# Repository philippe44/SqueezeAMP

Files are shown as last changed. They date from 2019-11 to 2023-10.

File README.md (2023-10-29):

# SqueezeAMP: an all-in-one audio sub-system

NOTE: for clarity reasons, I've created a branch 3.x which is the new default. I'll remove all references to PCB before 3.11 in that branch. Look at "master" to have history

This design can be used as a general all-in-one audio subsystem, but it's specially made to match the [SqueezeESP project](https://github.com/philippe44/squeezelite-esp32).
It includes the following:

- Espressif's WROVER board based on ESP32 WiFi/BT chipset (built-in antenna)
- WiFi / BT connectivity
- TI's TAS575x stereo class-D amplifier for up to 2x20W (careful with heat dissipation)
- Built-in battery charger (2 or 3 Li-Ion cells in serie) and automatic switch between battery and main
- Direct speaker output
- Jack 3.5mm for analogue line-out (with insertion detection) ==> <strong>this NOT supposed to be a headset output but it seems to drive enough for small 3 pins headphones at decent volume (need to check)</strong>
- SDPIF optical output
- Infrared Receiver
- Connector for 8 extra general purpose I/O (SPI, I2C, I2S, GPIO ...) ==> can add screen, buttons, rotary encoder ...
- 2 pins (1.27mm) on/off header (off mode consumes about 0.3mA on battery, a few tweaks can bring it down to 0.1 mA)
- 2 pins (1.27mm) GPI/sensor header (see ESP32 documentation about sensor_vn and sensor_vp)
- 2 pins (1.27mm) for 3.3V/GND
- 6 pins (2.54mm) header provide 3.3V (output), GND, reset and serial flash download (boot, rx, tx - which can be reused as general purpose IO)
- 2.5mm Power Jack with Vcc 5...16V (20V under certain conditions see note on power supply below)
- A/D for battery level measure
- Charge LED, bi-color LED

Looking at the board, TOP refers to the side that has the WROVER module and LEFT is where the Power Jack is located

# What can it do

With the squeezelite-esp32 software, you can

- Stream from LMS and send audio to the build-in amplifier, the line-out jack, the spdif connector or another bluetooth speaker. You can also use an external I2S DAC if you connect it to the general purpose 5/8 pins connector and tweak the software. Synchronization works.
- Stream from a Bluetooth device and send audio to the same outputs, except of course for sending to another bluetooth speaker ... There is no guarantee of audio/video synchronization at this point
- Stream from an AirPlay1 device (iPhone, iTunes ...) to the same outputs, including to a bluetooth speaker. Synchronization works.
- Add your own buttons, rotary encoder and map/combine them to various functions (play, pause, volume, next ...
- Use IR control by adding a simple receiver compatible with 38kHz device (no pullup resistor or capacitor needed)
- Add a display like this [one](https://www.buydisplay.com/i2c-blue-0-91-inch-oled-display-module-128x32-arduino-raspberry-pi) which can be directly connected to the 6-pins header. Currently SH1106, SSD1306, SSD1322, SSD1326/7, SSD1351, ST7735 and ST7789 displays are supported.

A small 0.91 display like [this one](https://www.aliexpress.com/item/1005001680040131.html) with [low profile connector](https://www.aliexpress.com/item/4000147221999.html) can be directly connected to the 6 pins 2.54 mm connector and nicely fits inside the case. Use the following settings 
- display_config -> I2C,driver=SSD1306,width=128,height=32
- i2c_config -> sda=3,scl=1,port=1,speed=600000

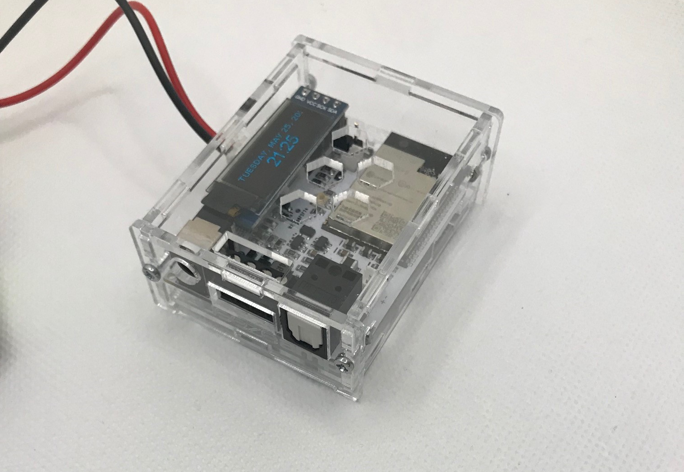
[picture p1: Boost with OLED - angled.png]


This casing is in the *case* repository and has been made by Chris Hill who deserves all credits for this really great design

# Tools, source and BOM

I'm using [diptrace](https://diptrace.com) for schematics and routing which is free up to 300 pins. I had to do a few custom components and patterns, let me know if they are missing or if you cannot use the free version, I'll try to do some export to other PCB formats if needed
You can order the PCB directly from PCBway [here](https://www.pcbway.com/)
There is an excel file with is the BOM extract from diptrace and another one that points to all components from DigiKey
The WROVER documentation can be found on [Espressif](http://www.espressif.com) site
Download tool is [here](https://www.espressif.com/en/support/download/other-tools)

## Connectors & WROVER pin assignments

There are 2 PCB versions, a basic and a boost option for each one (see below for basic/boot differences).

All connectors are through-holes so that you can not populate them and directly solder wires if you want to use the board inside another equipment (Under parenthesis is the WROVER pin number).

- J1: power jack
- J2: audio jack 
	- 4: (6 - IO34) Detect ==> has pull-up and should be set to ground to detect jack insertion
- J3: main header 
	- 1: GND
	- 2: 3.3V output
	- 3: TX (35) IO1
	- 4: RX (34) IO3
	- 5: EN/reset (3) ==> connect to RTS if possible
	- 6: Boot (25) IO0 ==> pull down at reset to enter download mode (connect to DTR if possible). It's also connected to the IR
- J4/J9: battery connector (double footprint)
	- 1: +
	- 2: -
- J5: speaker connector
	- 1: L+ (square pad)
	- 2: L-
	- 3: R-
	- 4: R+
- J6: IO extension connector (note that a right-angle and a straight version exist)
	- 1: (26) IO4
	- 2: (29) IO5
	- 3: (30) IO18
	- 4: (31) IO19
	- 5: (33) IO21
	- 6: (35) IO0/GND depending on S2
	- 7: (36) IO22
	- 8: (37) IO23
- J7: on/off (on when floating/open)	
	- 1: GND
	- 2: ENable ==> short with pin 1/GND to switch off 3.3V power
- J8: Input/Sensor connector (inputs only, no internal pull-up)
	- 1: (5) IO39
	- 2: (4) IO36
- J10: Power source
	- 1: 3.3V
	- 2: GND
- S2: select J6 pin 6 between GND and IO2
- Green LED: (14) IO12, active low
- Red LED: (16) IO13, active low
- TAS575x Speaker mute (13) IO14
- TAS575x Speaker fault (24) IO2
- TAS575x SCL/SDA: (11) IO26 / (12) IO27
- TAS575x I2S WS/SD/CLK: (10) IO25 / (8) IO32 / (9) IO33
- SPDIF: (23) IO15

<strong>Note that is no reverse polarity protection on the battery pins, so be careful as it will toast the power switch TPS22810 and probably the PCB itself. There is polarity protection on the main.</strong>

# Flash download

For at least initial download, you need a serial connection with ideally RX/TX/RTS/DTR and at least RX/TX. There is no build-in converter. 

Connect RX/TX to J3 pin header. If you don't have DTR/boot, you must connect DWL to ground while resetting (simply put a wire on pin 6 of J3 and connect it to any ground) and if don't have RTS/reset, press the tiny reset button or short the RST pin to ground. 

The esp32 will enter download and you'll be able to update the software, as described on the squeezelite-esp32 site. This procedure is rarely needed as the software supports OTA update.

Follow the instructions [here](https://github.com/philippe44/squeezelite-esp32) or have fun with your own software (see also espressif [guide](https://github.com/espressif/esptool/wiki/ESP32-Boot-Mode-Selection))

# Usage comments

Now that since displays, rotary encoder and buttons are supported by the firmware, you need power and more IOs. You can use power from J6 of course, but if you use it to directly connect a display like [this](https://www.amazon.com/MakerFocus-Display-SSD1306-3-3V-5V-Arduino/dp/B0761LV1SD/) (and remember that since PCB 3.x, it is a direct board-to-board fit) you might want another source so you can use J10. You can as well use extended J6 pin above or below to grab 3.3V from there.

The benefit of changing J6's pin 6 to GND is, for example, to bring a GND wire to a button expansion board of your own. There is no need of Vcc as the ESP32 has optional pull-up. Still, if you want a Vcc, you can use one GPIO as a supply, with a maximum of 40mA per pin. That would allow you to use a single connector for the IOs and a display on J6. You could have Vcc, GND, 3 pins for a rotary, play, back, vol+, vol- which is a pretty good UI.

All 2-pin connectors have been changed to support standard 1.25mm connectors like [this](https://www.ebay.ca/itm/50Set-Micro-JST1-25-2Pin-Connector-Plug-with-Wire-150mm-28AWG/182056647596) so that you can find pre-wired female cables and not go through the pain of using these tiny crimps. The male header is a really tight fit on the PCB, but it works. You can also always solder wires if you want  to.

<strong>All GPIO have internal pull-up/down that you can set by software, so in most cases you don't need to bring power to buttons/encoder board, except if you use J8. These are inputs only and have no pull-up, so you need to add them on your IO board.</strong>

According to TAS57xx datasheet, if you short L+/L- and R+/R- you can use the chip in post-filtered mono BTL mode. Sounds a bit strange and I've not tried as of this writing, but if it might be handy to do a mono (more powerful) speaker.

# Populating options

System is modular and you can pretty much build each sub-part independently. 

If you don't want battery, don't populate charger, undervoltage detection and power OR and boost (on the boost option, see below). This is all top upper and middle right & left side of the PCB. You can short the large Schottky diode on the bottom side, but I recommend you keep it just in case.

If you don't want the amplifier, don't populate the bottom side, except for the power diode and the optical connector's decoupling capacitor (if you want SPDIF optical). In that case, note that the analogue output will *not* be available.

The SPDIF is always available, it just requires the WROVER module (which should at least always be here ...). 

The battery connector is the angled version of the classical short 2 pins JST. You can use a longer version if you want the pins to extend a bit beyong the PCB (like the jack connector). You can also use a vertical connector [here]( https://www.digikey.ca/product-detail/en/jst-sales-america-inc/B2B-XH-A(LF)(SN)/455-2247-ND/1651045)

# Power options

I've been through a lot of back and forth about power. To charge 3-LiIon cells, the LT3652 requires at least 16V (Vbatt + 3.3V). But when powered with 16V, the TAS575x produces a fair bit of heat while it almost does none at 12V. Similar, the original design charging rate was 1A, but that got the LT3652 and inductor super hot, so I've reduced is to 0,66A (8W max). The rate is 0.1/R7 so you can tweak it if you want, on paper the design is capable of 1A.

When using 2 cells, a 12V power supply is sufficient which is ideal for the TAS575x, but then when used on battery the audio power is much less as the battery will provide 6~8.4V. Charging rate in that case is 0.75A. 

So finally, I have 2 PCB options, the boost being the most versatile one but the most expensive as well. If you decide to not populate the battery charging, you can skip the rest of that section.

## Basic design

2 cells mode is the simplest option. Power supply can be 12-20V, but 12V is recommended to optimize heat dissipation unless you want maximum amplifier power.  

In 3 cells mode, the power supply must be 16-20V and a few components must be changed

- R8 (412k) ==> 340k
- R9 (634k)==> 953k
- R11 (25.5k) ==> 15.8k
- D5 (2.4V Zener) ==> 5~8V Zener (I use 5.1)
- R7 (0.13) ==> 0.16

In both case, if you limit the power supply to 16V, you can use 25V for all capacitors which saves a fair bit of cost for the 22µF. It does not change anything for others (indeed 50V can a be cheaper option for 100nF for example).

## Boost design

This PCB option include a boost converter so that power supply can be 12V even in 3 cells modes. With that, the TAS575x is always powered with ~12V which is the ideal ratio heat/amplifier power. The boost converter will up the power supply to comply with LT3652 requirement of Vcc > VBat + 3.3V. You could even power it with 5V and it will charge the 3-cells battery **but** it will still power the amplifier at 5V (or whatever you put in).

## (Executive) Summary

- don't want battery, use the basic version and maybe do not populate all the charger-related components
	- want to minimize heat: use 12V
	- want maximum audio power: use up to 20V
- want battery
	- don't need too much audio power when battery powered: choose basic (2 cells) and power it with 12V. 
	- want more audio power: 
		- don't care much about amplifier's heat: choose basic (3 cells) and power it with 16+V (put a sink on the TAS575X and the exposed pad). 
	- want to minimize amplifier's heat, choose boost (3 cells) and power it with 12V
	- want simply to power with less than 12V, choose boost (2 or 3 cells). 

# Limitation & Disclaimer

This contains a power amplifier and a charger on a small board, so it gets pretty hot when used at high power. I've added a small exposed copper area where you can add a heatsink and also use a fan to help cooling down, but I cannot guarantee that this design works well and safely with continuous high volume. My own use is at moderate volume.

Similarly, the charger is for Li-Ion and such cells have inherent safety issues. It's using a LT3652, which is a good charger that takes care of battery maintenance, but there is no thermal management, so be careful and ALWAYS use protected Li-Ion cells. There is battery undervoltage detection on board so that the systems shuts off when battery voltage is too low. There is no under voltage detection for main supply.

<strong>This is by no mean a professional design so use it at your own risk. I will not be liable for any issue caused by that board</strong>. I'm making it public in case somebody with enough knowledge will find it useful, so know what you're doing first. Similarly, this is not an audiophile design, so please do not complain or ask me for some linear power or 32 bits / DSD insanities. The SqueezeESP software can do 16 bits @ 192 kHz which is way more than enough, in fact 48kHz/16 should be sufficient. 

Credits to @Aki7 for the picture below
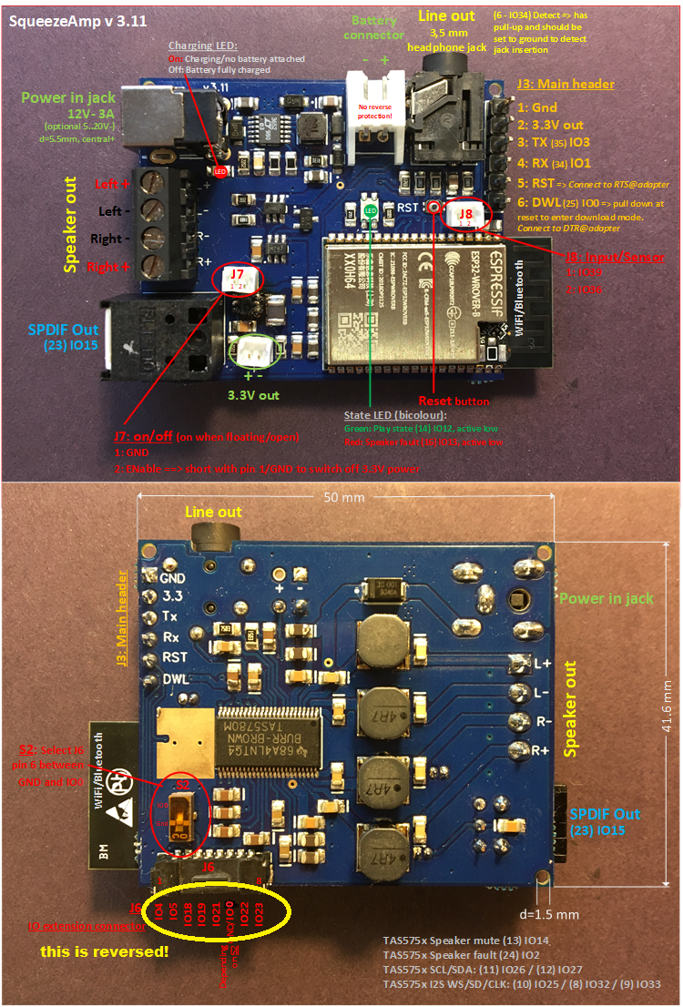
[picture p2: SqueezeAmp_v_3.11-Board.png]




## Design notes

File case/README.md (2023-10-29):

The V1 is an old casing that has not been continued.

The V2 is made of 6 pieces and requires 4 screws to be assembled. It exists as well in thing and thick (battery) versions.

There is a root DXF file that contains all the drawings for acrylic laser cuts, tolerances should be part of cutting.

The DXF has been adjusted to a 3D version that adds tolerances for 3D printing with a 2mm thickness.

A few STL are provides as well

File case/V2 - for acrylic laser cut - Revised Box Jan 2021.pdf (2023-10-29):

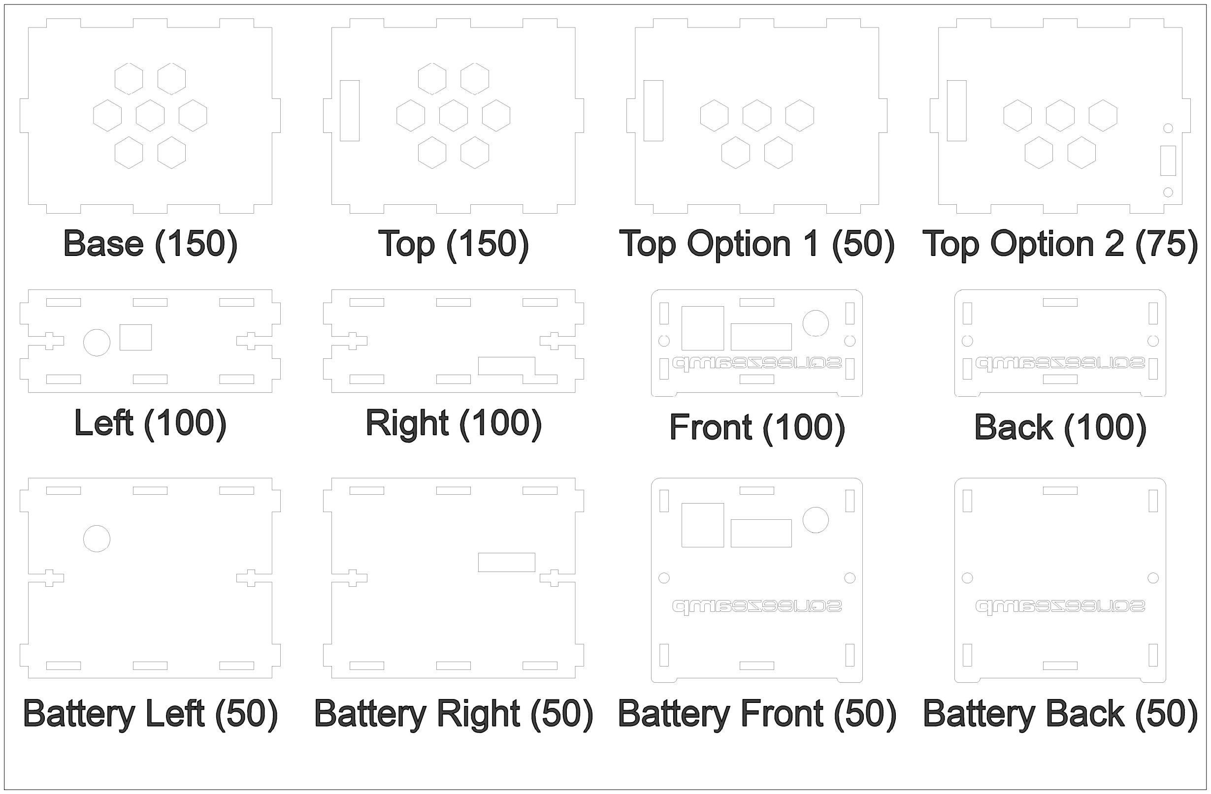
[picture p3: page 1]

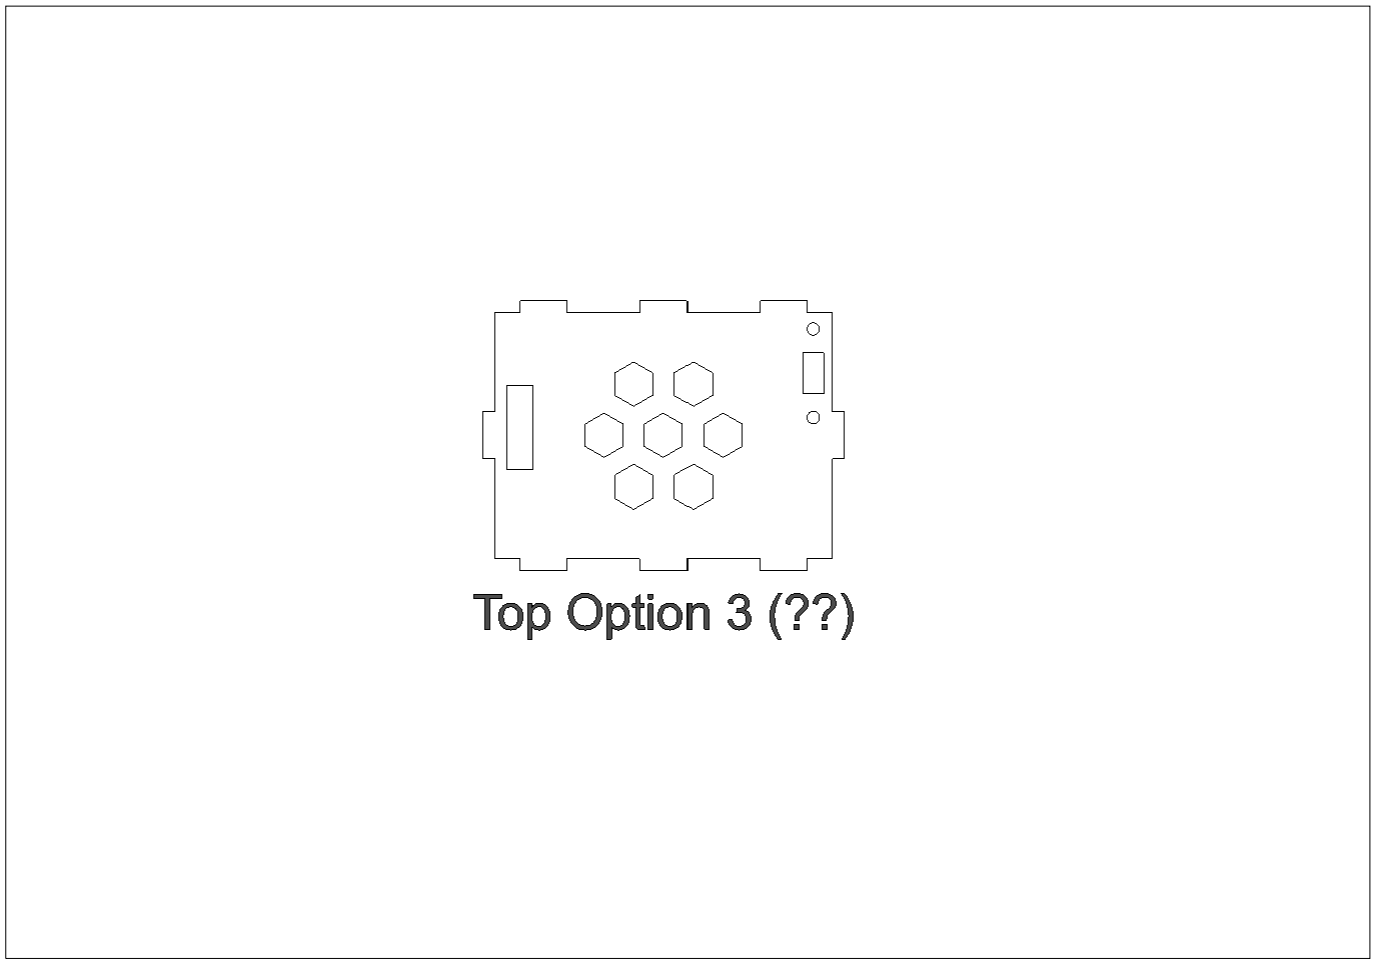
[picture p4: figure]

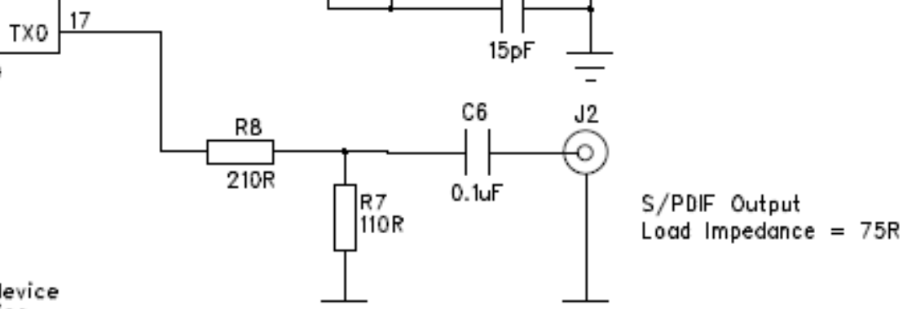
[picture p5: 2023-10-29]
ttl2coax.png

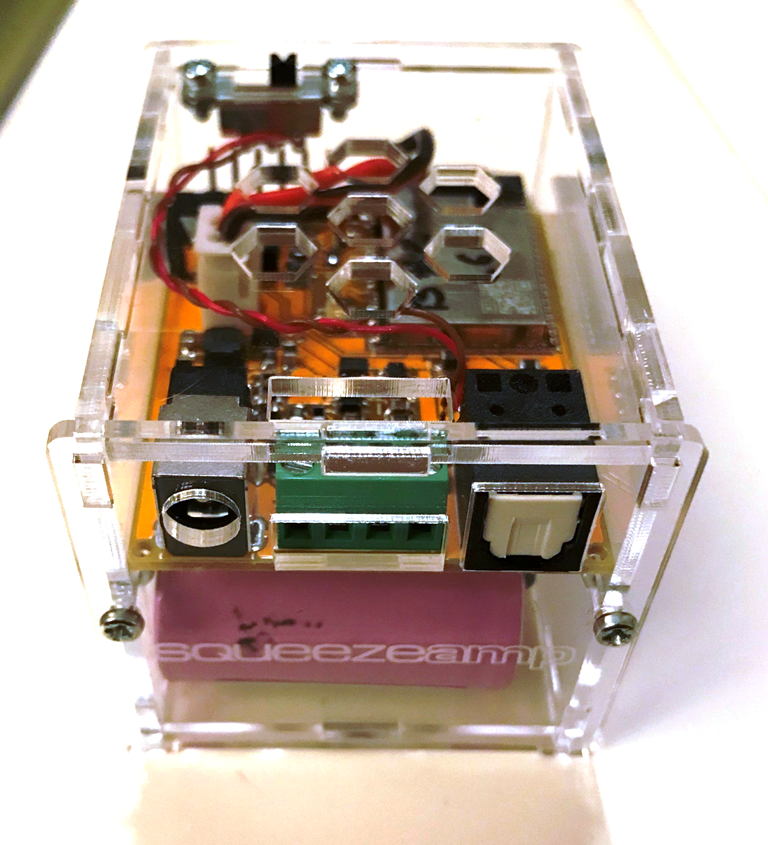
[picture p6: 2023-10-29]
Thick.png

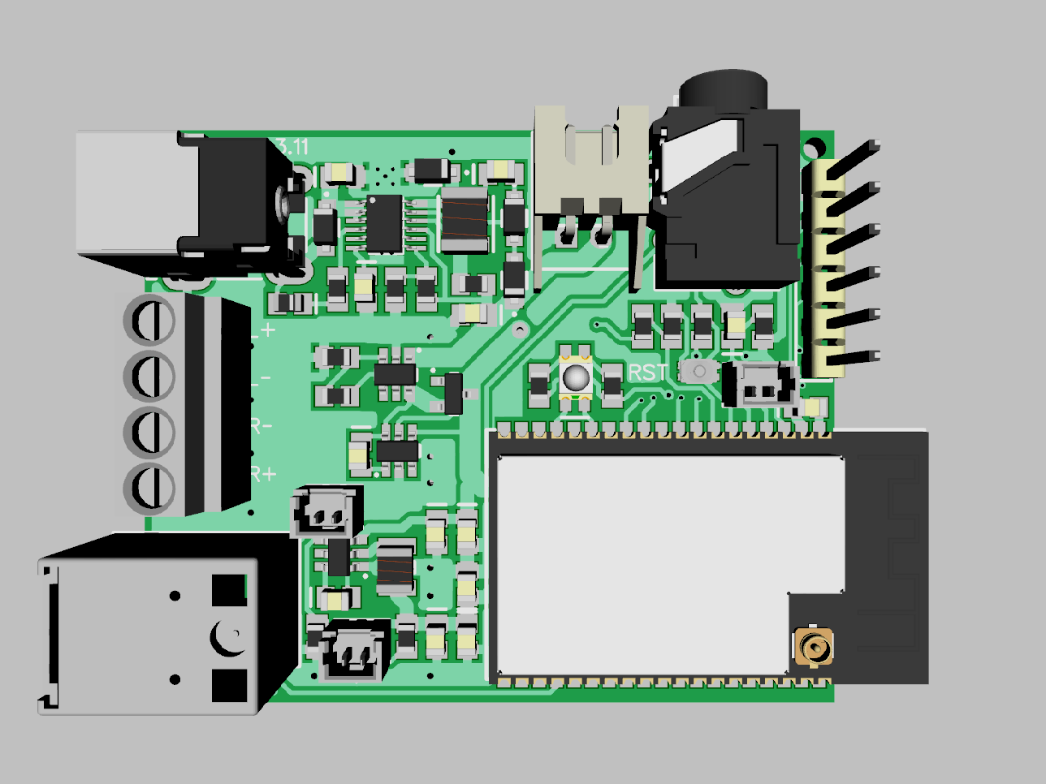
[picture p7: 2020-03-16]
top.png

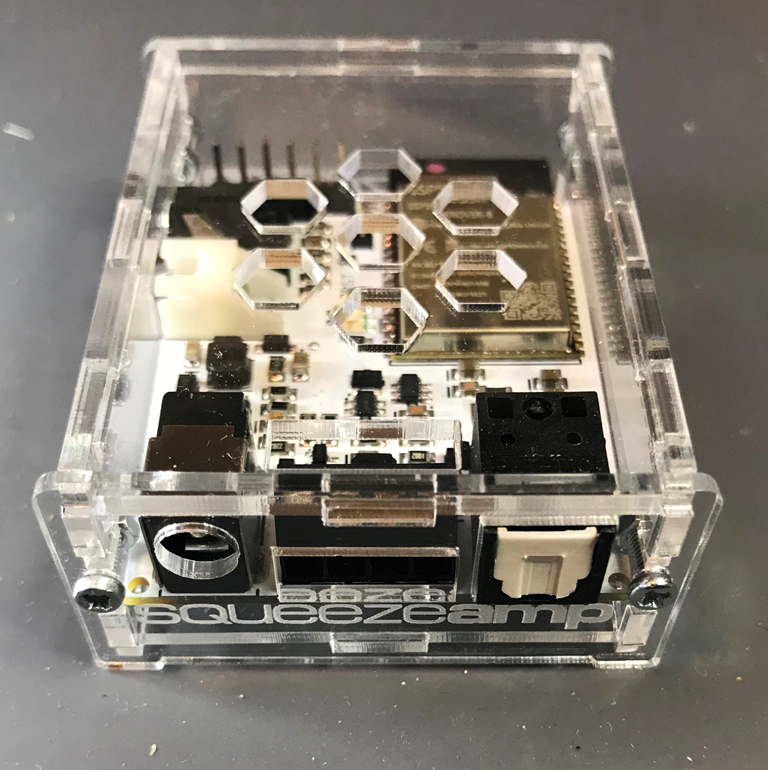
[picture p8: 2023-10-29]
Thin.png

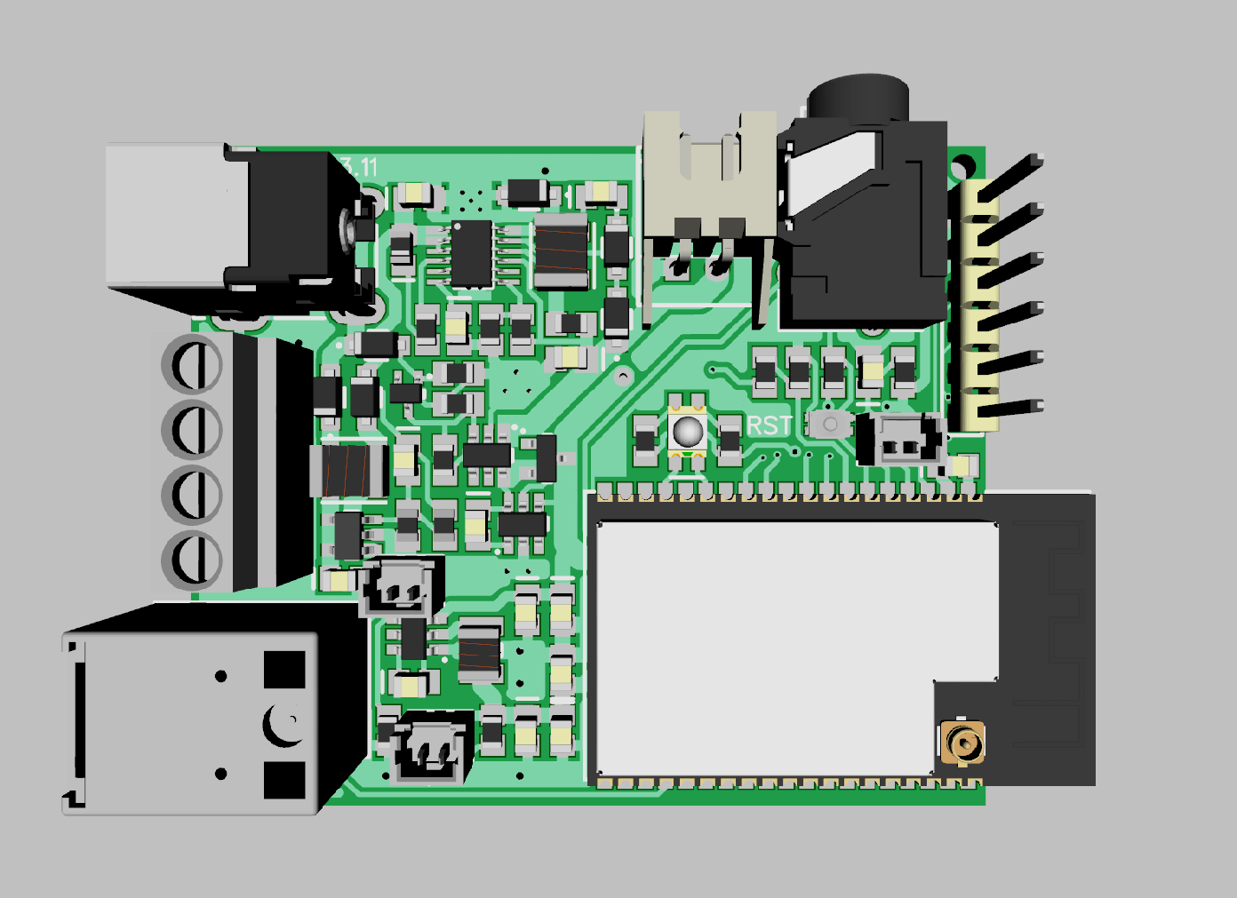
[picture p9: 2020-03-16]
top-boost.png

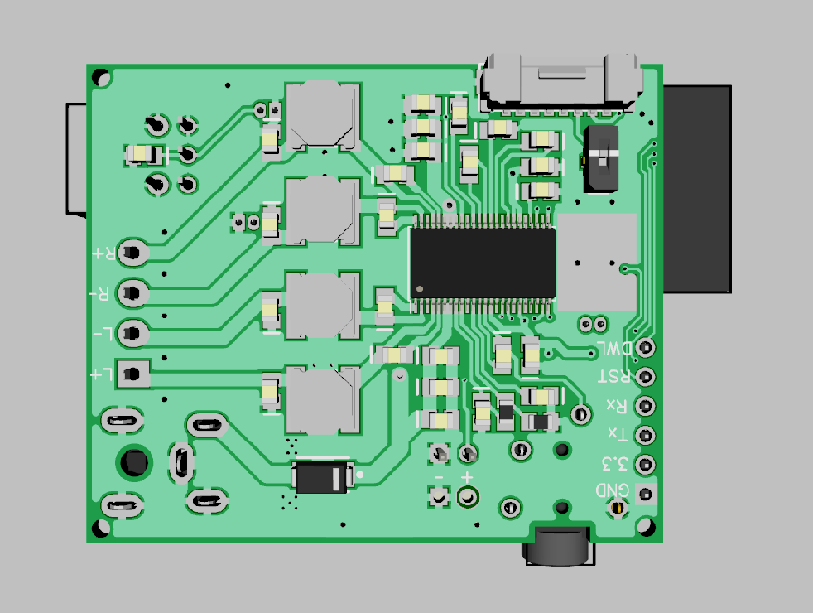
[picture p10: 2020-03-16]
bottom.png

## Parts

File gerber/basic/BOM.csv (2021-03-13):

RefDes | Value | Name | Part
C1 | 22uF 35V | CAP_0805 | https://www.digikey.ca/product-detail/en/tdk-corporation/C2012X5R1V226M125AC/445-14428-1-ND/3956094
C2 | 1uF 35V | CAP_0805 | https://www.digikey.ca/product-detail/en/samsung-electro-mechanics/CL21B105KBFNFNE/1276-2928-1-ND/3891014
C3 | 100nF 35V | CAP_0805 | https://www.digikey.ca/product-detail/en/yageo/CC0805ZRY5V9BB104/311-1361-1-ND/2103145
C4 | 100nF 35V | CAP_0805 | https://www.digikey.ca/product-detail/en/yageo/CC0805ZRY5V9BB104/311-1361-1-ND/2103145
C5 | 22uF 35V | CAP_0805 | https://www.digikey.ca/product-detail/en/tdk-corporation/C2012X5R1V226M125AC/445-14428-1-ND/3956094
C6 | 22uF 35V | CAP_0805 | https://www.digikey.ca/product-detail/en/tdk-corporation/C2012X5R1V226M125AC/445-14428-1-ND/3956094
C7 | 22uF 35V | CAP_0805 | https://www.digikey.ca/product-detail/en/tdk-corporation/C2012X5R1V226M125AC/445-14428-1-ND/3956094
C8 | 22uF 35V | CAP_0805 | https://www.digikey.ca/product-detail/en/tdk-corporation/C2012X5R1V226M125AC/445-14428-1-ND/3956094
C9 | 1uF 35V | CAP_0805 | https://www.digikey.ca/product-detail/en/samsung-electro-mechanics/CL21B105KBFNFNE/1276-2928-1-ND/3891014
C10 | 22uF 35V | CAP_0805 | https://www.digikey.ca/product-detail/en/tdk-corporation/C2012X5R1V226M125AC/445-14428-1-ND/3956094
C11 | 1uF 35V | CAP_0805 | https://www.digikey.ca/product-detail/en/samsung-electro-mechanics/CL21B105KBFNFNE/1276-2928-1-ND/3891014
C12 | 1uF 35V | CAP_0805 | https://www.digikey.ca/product-detail/en/samsung-electro-mechanics/CL21B105KBFNFNE/1276-2928-1-ND/3891014
C13 | 1uF 35V | CAP_0805 | https://www.digikey.ca/product-detail/en/samsung-electro-mechanics/CL21B105KBFNFNE/1276-2928-1-ND/3891014
C14 | 2u2F 35V | CAP_0805 | https://www.digikey.ca/product-detail/en/samsung-electro-mechanics/CL21A225KBFNNNE/1276-6702-1-ND/5961561
C15 | 2u2F 35V | CAP_0805 | https://www.digikey.ca/product-detail/en/samsung-electro-mechanics/CL21A225KBFNNNE/1276-6702-1-ND/5961561
C16 | 1uF 35V | CAP_0805 | https://www.digikey.ca/product-detail/en/samsung-electro-mechanics/CL21B105KBFNFNE/1276-2928-1-ND/3891014
C17 | 220nF 35v | CAP_0805 | https://www.digikey.ca/product-detail/en/wurth-electronics-inc/885012207100/732-7675-1-ND/5454302
C18 | 2u2F 35V | CAP_0805 | https://www.digikey.ca/product-detail/en/samsung-electro-mechanics/CL21A225KBFNNNE/1276-6702-1-ND/5961561
C19 | 2u2F 35V | CAP_0805 | https://www.digikey.ca/product-detail/en/samsung-electro-mechanics/CL21A225KBFNNNE/1276-6702-1-ND/5961561
C20 | 680nF 35V | CAP_0805 | https://www.digikey.ca/product-detail/en/tdk-corporation/C2012X5R1H684K125AB/445-14413-6-ND/3960509
C21 | 1uF 35V | CAP_0805 | https://www.digikey.ca/product-detail/en/samsung-electro-mechanics/CL21B105KBFNFNE/1276-2928-1-ND/3891014
C22 | 220nF 35V | CAP_0805 | https://www.digikey.ca/product-detail/en/wurth-electronics-inc/885012207100/732-7675-1-ND/5454302
C23 | 220nF 35V | CAP_0805 | https://www.digikey.ca/product-detail/en/wurth-electronics-inc/885012207100/732-7675-1-ND/5454302
C24 | 220nF 35V | CAP_0805 | https://www.digikey.ca/product-detail/en/wurth-electronics-inc/885012207100/732-7675-1-ND/5454302
C25 | 680nF 35V | CAP_0805 | https://www.digikey.ca/product-detail/en/tdk-corporation/C2012X5R1H684K125AB/445-14413-6-ND/3960509
C26 | 680nF 35V | CAP_0805 | https://www.digikey.ca/product-detail/en/tdk-corporation/C2012X5R1H684K125AB/445-14413-6-ND/3960509
C27 | 680nF 35V | CAP_0805 | https://www.digikey.ca/product-detail/en/tdk-corporation/C2012X5R1H684K125AB/445-14413-6-ND/3960509
C28 | 680nF 35V | CAP_0805 | https://www.digikey.ca/product-detail/en/tdk-corporation/C2012X5R1H684K125AB/445-14413-6-ND/3960509
C29 | 22uF 25V | CAP_0805 | https://www.digikey.ca/product-detail/en/tdk-corporation/C2012X5R1V226M125AC/445-14428-1-ND/3956094
C30 | 22uF 35V | CAP_0805 | https://www.digikey.ca/product-detail/en/tdk-corporation/C2012X5R1V226M125AC/445-14428-1-ND/3956094
C31 | 100nF 35V | CAP_0805 | https://www.digikey.ca/product-detail/en/yageo/CC0805ZRY5V9BB104/311-1361-1-ND/2103145
C32 | 1uF 35V | CAP_0805 | https://www.digikey.ca/product-detail/en/samsung-electro-mechanics/CL21B105KBFNFNE/1276-2928-1-ND/3891014
C36 | 100nF 35V | CAP_0805 | https://www.digikey.ca/product-detail/en/yageo/CC0805ZRY5V9BB104/311-1361-1-ND/2103145
C41 | 22uF 35V | CAP_0805 | https://www.digikey.ca/product-detail/en/tdk-corporation/C2012X5R1V226M125AC/445-14428-1-ND/3956094
C42 | 100nF 35V | CAP_0805 | https://www.digikey.ca/product-detail/en/yageo/CC0805ZRY5V9BB104/311-1361-1-ND/2103145
C43 | 100nF 35V | CAP_0805 | https://www.digikey.ca/product-detail/en/yageo/CC0805ZRY5V9BB104/311-1361-1-ND/2103145
C44 | 22uF 35V | CAP_0805 | https://www.digikey.ca/product-detail/en/tdk-corporation/C2012X5R1V226M125AC/445-14428-1-ND/3956094
C45 | 100nF 35V | CAP_0805 | https://www.digikey.ca/product-detail/en/yageo/CC0805ZRY5V9BB104/311-1361-1-ND/2103145
D1 | LED | 0805 | https://www.digikey.ca/product-detail/en/kingbright/APT2012LSECK-J3-PRV/754-1935-1-ND/5177465
D2 | Schottky 40V 2A | SOD123F | https://www.digikey.ca/product-detail/en/diodes-incorporated/B240S1F-7/B240S1F-7DICT-ND/7784165
D3 | Schottky 40V 2A | SOD123F | https://www.digikey.ca/product-detail/en/diodes-incorporated/B240S1F-7/B240S1F-7DICT-ND/7784165
D4 | Diode 100mA | SOD123F | https://www.digikey.ca/product-detail/en/diodes-incorporated/BAV21HWF-7/BAV21HWF-7DICT-ND/5451809
D5 | Zener 2.4V 100mA | SOD123F | https://www.digikey.ca/product-detail/en/BZT52B2V4+RHG/BZT52B2V4RHGCT-ND/7357321
D6 | Schottky 40V 3A | MBRS340 | https://www.digikey.ca/product-detail/en/diodes-incorporated/B340A-13-F/B340A-FDICT-ND/725054
D8 | Dual LED | 754-1965-1-ND | https://www.digikey.ca/product-detail/en/kingbright/APBD3224LSURKZGKC/754-1965-1-ND/5803684
J1 | Power Jack 2.1 | PJ-047AH | https://www.digikey.ca/product-detail/en/cui-devices/PJ-047AH/CP-047AH-ND/1644577
J2 | 3.5mm Jack 4 points | SJ-43514 | https://www.digikey.ca/product-detail/en/cui-inc/SJ-43514/CP-43514-ND/368146
J3 | 6 pins header 2.54 | CONN | https://www.digikey.ca/product-detail/en/amphenol-icc-fci/68000-406HLF/609-3263-ND/1878471
J4 | Header 2 pin 2.54 mm | Header | https://www.digikey.ca/product-detail/en/jst-sales-america-inc/S2B-XH-A-1(LF)(SN)/455-4226-ND/9961922
J5 | Term Header 4 Pos | WM7860-ND | https://www.digikey.ca/product-detail/en/molex/0393570004/WM7860-ND/1280711
J6 | Molex ML+ 8 pins | Molex MicroLockPlus 8 | https://www.digikey.ca/product-detail/en/molex/5055670871/WM17115CT-ND/7908449
J7 | Header 2 pins 1.27 | 125SH-B-02-TS-SQ | https://www.digikey.ca/product-detail/en/125SH-B-02-TS/2057-125SH-B-02-TS-ND/9830561/
J8 | Header 2 pins 1.27 | 125SH-B-02-TS | https://www.digikey.ca/product-detail/en/125SH-B-02-TS/2057-125SH-B-02-TS-ND/9830561/
J9 | Header 2 pin 2.54 mm | Header | https://www.digikey.ca/product-detail/en/jst-sales-america-inc/S2B-XH-A-1(LF)(SN)/455-4226-ND/9961922
J10 | Header 2 pins 1.27 | 125SH-B-02-TS-SQ | https://www.digikey.ca/product-detail/en/125SH-B-02-TS/2057-125SH-B-02-TS-ND/9830561/
L1 | 4.7uH | 1255AY-4R7M=P3 | https://www.digikey.ca/product-detail/en/murata-electronics-north-america/1255AY-4R7M=P3/490-10812-1-ND/5271554
L2 | 4.7uH | 1255AY-4R7M=P3 | https://www.digikey.ca/product-detail/en/murata-electronics-north-america/1255AY-4R7M=P3/490-10812-1-ND/5271554
L3 | 4.7uH | 1255AY-4R7M=P3 | https://www.digikey.ca/product-detail/en/murata-electronics-north-america/1255AY-4R7M=P3/490-10812-1-ND/5271554
L4 | 4.7uH | 1255AY-4R7M=P3 | https://www.digikey.ca/product-detail/en/murata-electronics-north-america/1255AY-4R7M=P3/490-10812-1-ND/5271554
L5 | 10uH | ASPI-4030S | https://www.digikey.ca/product-detail/en/abracon-llc/ASPI-4030S-100M-T/535-12314-1-ND/4214914
L6 | 22uH | IND_1210 | https://www.digikey.ca/product-detail/en/taiyo-yuden/CBC3225T220MR/587-1626-1-ND/1008241
Q1 | MOFSET-N 2.5A 60V | SOT-23F | https://www.digikey.ca/products/en?keywords=SSM3K318RLFDKR-ND
R1 | 100k | RES_0805 | https://www.digikey.ca/product-detail/en/yageo/RC0805FR-07100KL/311-100KCRCT-ND/730491
R2 | 22k | RES_0805 | https://www.digikey.ca/product-detail/en/yageo/RC0805FR-0722KL/311-22.0KCRCT-ND/730683
R3 | 22k | RES_0805 | https://www.digikey.ca/product-detail/en/yageo/RC0805FR-0722KL/311-22.0KCRCT-ND/730683
R4 | 150K | RES_0805 | https://www.digikey.ca/product-detail/en/yageo/RC0805FR-07150KL/311-150KCRCT-ND/730561
R5 | 270 | RES_0805 | https://www.digikey.ca/product-detail/en/yageo/RC0805JR-07270RL/311-270ARCT-ND/731238
R6 | 680 | RES_0805 | https://www.digikey.ca/product-detail/en/yageo/RC0805FR-07680RL/311-680CRCT-ND/731048
R7 | 0.13 | RES_0805 | https://www.digikey.ca/product-detail/en/yageo/RL0805FR-070R13L/311-.13SCT-ND/1037214
R8 | 634k - 0.1% | RES_0805 | https://www.digikey.ca/en/products/detail/panasonic-electronic-components/ERA-6AEB6343V/3075213
R9 | 412k - 0.1% | RES_0805 | https://www.digikey.ca/en/products/detail/panasonic-electronic-components/ERA-6AEB4123V/3075129
R10 | 110k (0.1%) | RES_0805 | https://www.digikey.ca/product-detail/en/yageo/RC0805FR-07110KL/311-110KCRCT-ND/730507
R11 | 25.5k | RES_0805 | https://www.digikey.ca/product-detail/en/RC0805FR-0725K5L/311-25.5KCRCT-ND/730715
R13 | 750k | RES_0805 | https://www.digikey.ca/product-detail/en/yageo/RC0805FR-07750KL/311-750KCRCT-ND/731082
R14 | 10k | RES_0805 | https://www.digikey.ca/product-detail/en/yageo/RC0805FR-0710KL/311-10.0KCRTR-ND/727535
R15 | 10k | RES_0805 | https://www.digikey.ca/product-detail/en/yageo/RC0805FR-0710KL/311-10.0KCRTR-ND/727535
R16 | 174k | RES_0805 | https://www.digikey.ca/product-detail/en/yageo/RC0805FR-07174KL/311-174KCRCT-ND/730587
R17 | 10k | RES_0805 | https://www.digikey.ca/product-detail/en/yageo/RC0805FR-0710KL/311-10.0KCRTR-ND/727535
S1 | Reset SW | EVPBB | https://www.digikey.ca/product-detail/en/panasonic-electronic-components/EVP-BB2A9B000/P19888CT-ND/6212411
S2 | GPIO select | CJS-1200TA | https://www.digikey.ca/product-detail/en/nidec-copal-electronics/CJS-1200TA/563-1021-1-ND/948401
U1 | Buck DC/DC | TPS54202 | https://www.digikey.ca/product-detail/en/texas-instruments/TPS54202DDCT/296-44151-1-ND/6021980
U2 | TAS57xx | TAS57xx | https://www.digikey.ca/product-detail/en/texas-instruments/TAS5780MDCAR/296-51626-1-ND/9745989
U3 | Charger | LT3652EMSE | https://www.digikey.ca/product-detail/en/linear-technology-analog-devices/LT3652EMSE-PBF/LT3652EMSE-PBF-ND/2225686
U4 | Diode Controller | LM74700-Q1 | https://www.digikey.ca/product-detail/en/texas-instruments/LM74700QDBVTQ1/296-53420-1-ND/9953065
U5 | SPDIF plug | PLT133/10W | https://www.digikey.ca/product-detail/en/everlight-electronics-co-ltd/PLT133-T10W/1080-1430-ND/2693977
U6 | ESP32-WROVER | ESP32-WROVER | https://www.digikey.ca/product-detail/en/espressif-systems/ESP32-WROVER-B-(M213DH6464PC3Q0)/1904-1034-1-ND/9857845
U7 | Power Switch | TPS22810 | https://www.digikey.ca/product-detail/en/texas-instruments/TPS22810DBVR/296-45297-1-ND/6599926

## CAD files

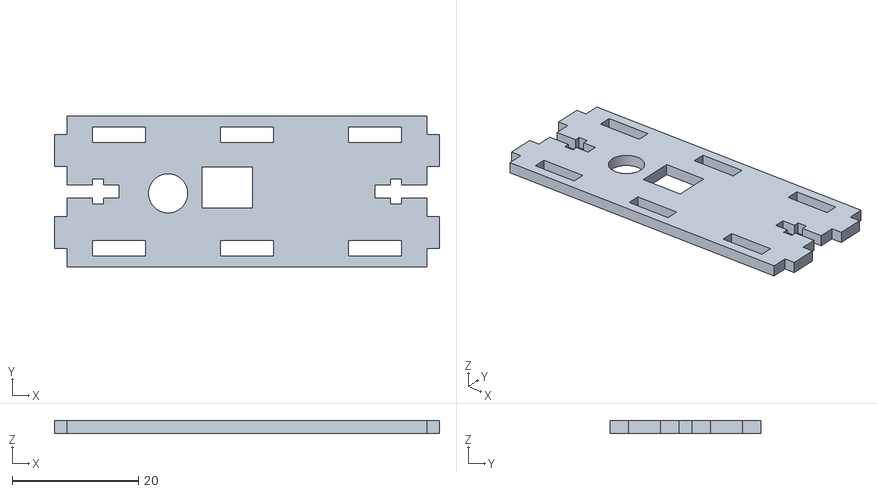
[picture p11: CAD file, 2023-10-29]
case/V2 - Thin Left.stl
61.0 x 24.0 x 2.00

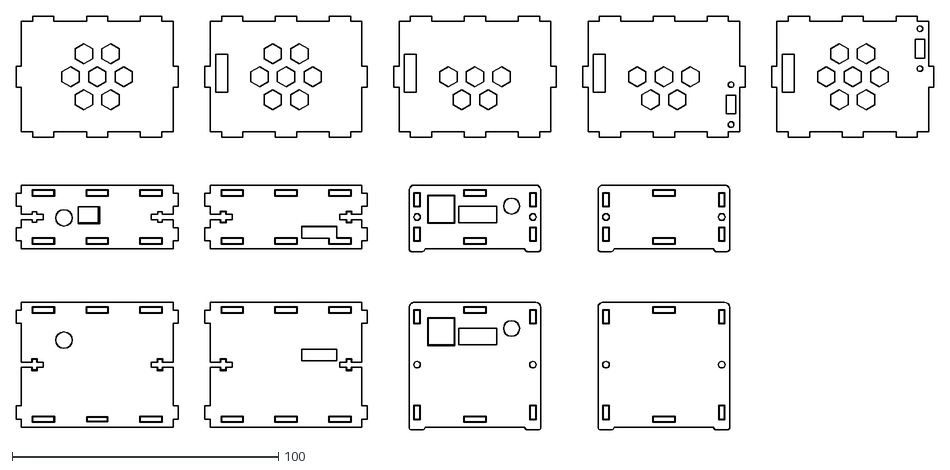
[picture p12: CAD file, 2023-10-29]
case/V2 - All Parts (3D adjusted, no logo).dxf
345.0 x 155.5

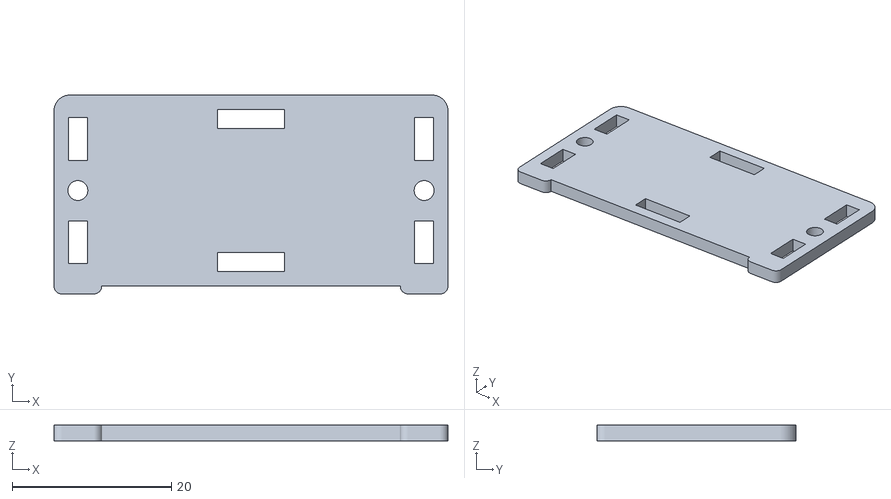
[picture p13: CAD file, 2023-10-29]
case/V2 - Thin Back.stl
49.5 x 25.0 x 2.00

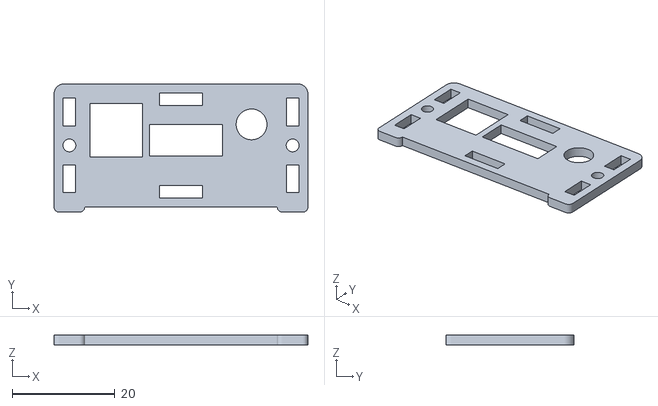
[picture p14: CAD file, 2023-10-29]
case/V2 - Thin Front.stl
49.5 x 25.0 x 2.00

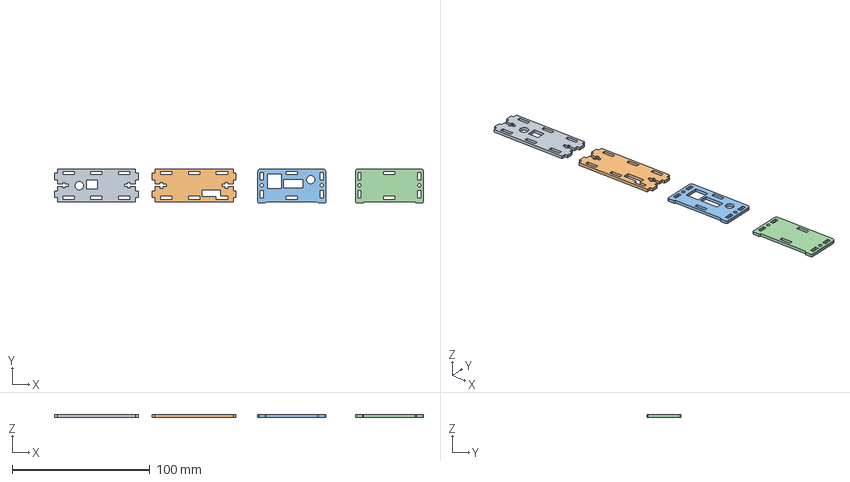
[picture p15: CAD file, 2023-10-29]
case/V2 - Thin Sides (3D adjusted).stp
268.3 x 25.0 x 2.00 mm

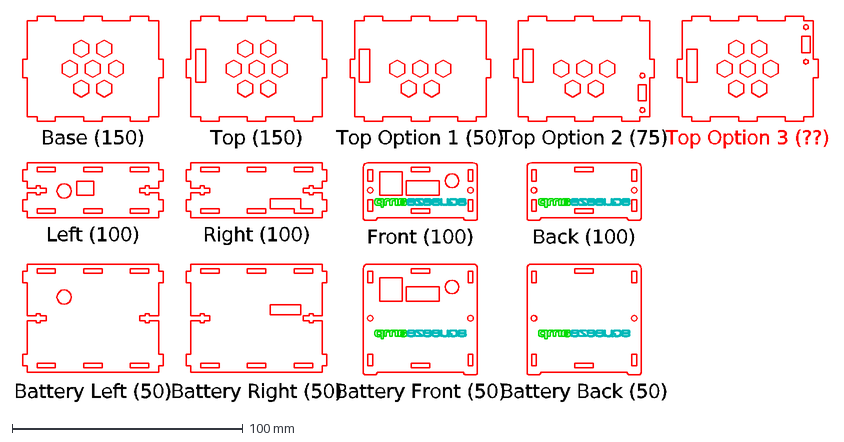
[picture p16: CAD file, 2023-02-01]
case/V2 - Revised Box Jan 2021.dxf
Base (150)
Top (150)
Top Option 1 (50)
Top Option 2 (75)
Left (100)
Right (100)
Front (100)
Back (100)
Battery Back (50)
Battery Front (50)
Battery Left (50)
Battery Right (50)
Top Option 3 (??)

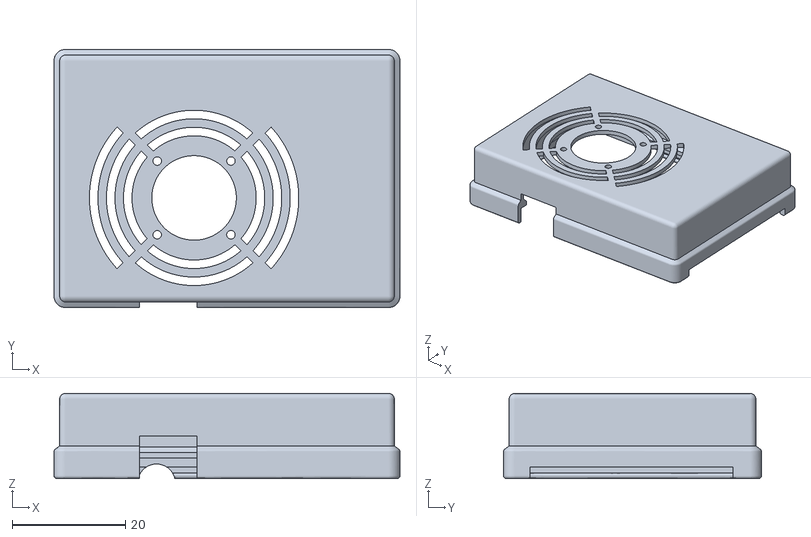
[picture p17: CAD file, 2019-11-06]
case/V1 - Lid with 16mm fan.stl
61.0 x 45.5 x 15.0

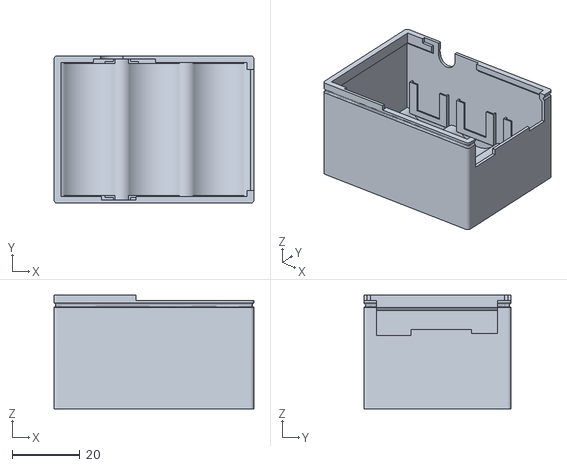
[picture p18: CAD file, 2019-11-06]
case/V1 - 3x18350.stl
59.0 x 43.5 x 33.6

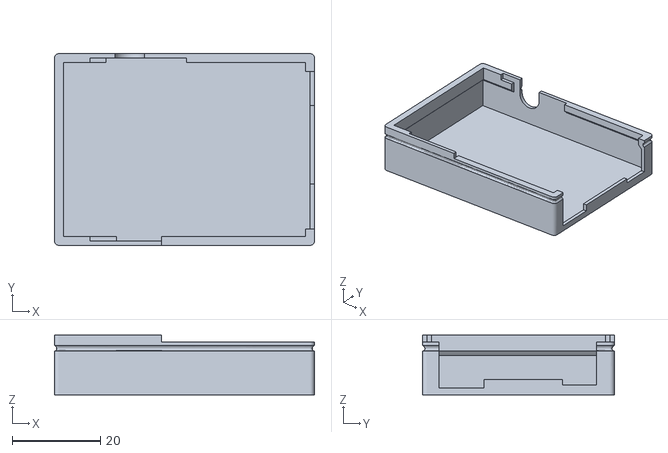
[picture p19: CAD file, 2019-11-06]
case/V1 - Basic base.stl
59.0 x 43.5 x 13.6

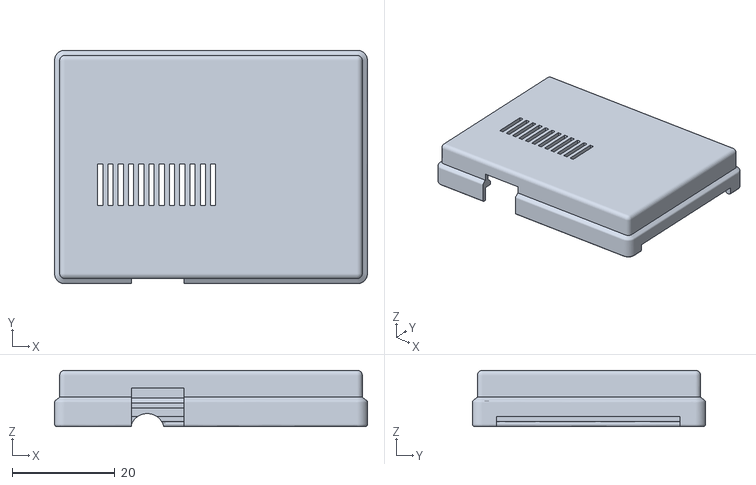
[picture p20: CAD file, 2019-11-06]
case/V1- 1mm taller lid with vent.stl
61.0 x 45.5 x 11.0

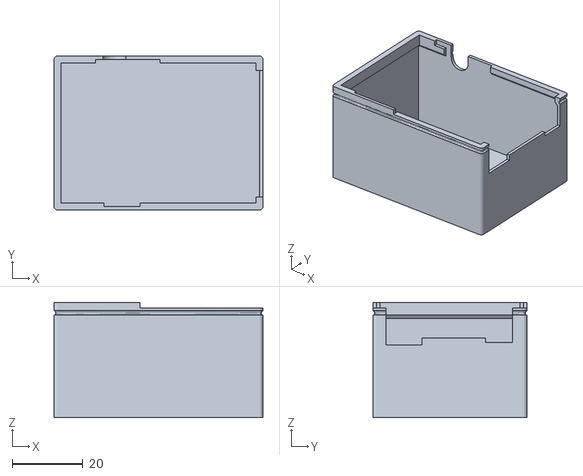
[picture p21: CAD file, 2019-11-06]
case/V1 - Empty Box.stl
59.0 x 43.5 x 32.6

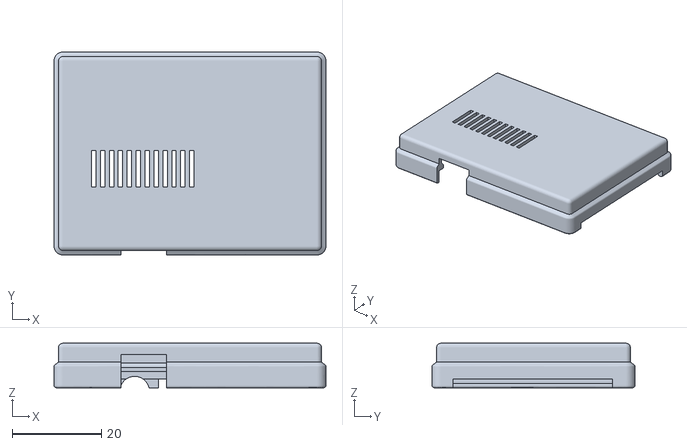
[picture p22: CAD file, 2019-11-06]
case/V1 - Lid with vent and side entry.stl
61.0 x 45.5 x 10.00

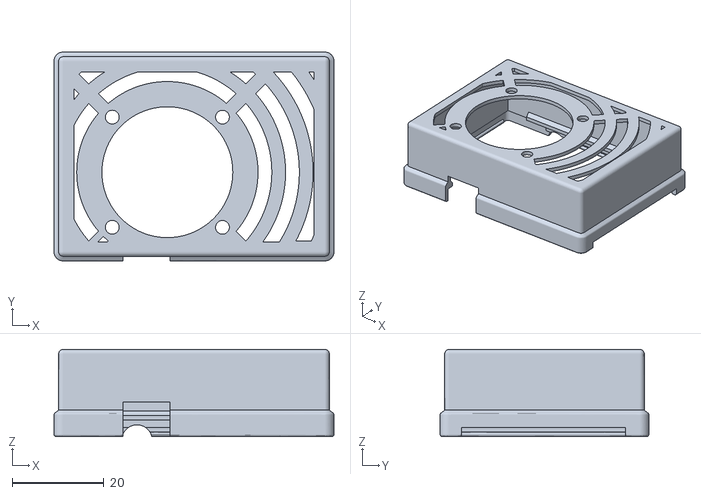
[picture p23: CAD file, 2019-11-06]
case/V1 - Lid with 30mm fan.stl
61.0 x 45.5 x 19.0

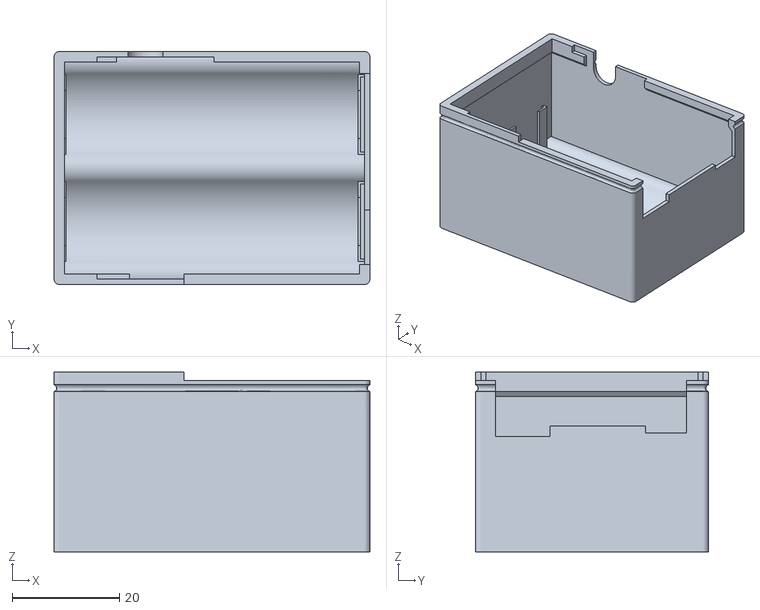
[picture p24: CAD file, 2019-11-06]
case/V1 - 2x18500.stl
59.0 x 43.5 x 33.6

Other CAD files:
case/V2 - Thin Right.stl
case/V1 - Basic base with side entry.stl
case/V1 - .stl

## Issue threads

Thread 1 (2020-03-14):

TAS5754 or TAS5780 and programmability

infnorm, 2020-03-14:
Your project is amazing, I'm wondering if there is any advantage for the TAS5780 vs TAS5754. It seems TAS5780 is fixed function and TAS5754 is more programmable DSP. Is it possible to program the DSP without the TI realpath software or to use the AMP without it? It seems like you need to setup a program by i2c for the TAS5754, and not all the registers are documented to setup a HybridFlow program. It seems like you could maybe get it working by setting the register on the top of page 74 http://www.ti.com/lit/ds/slas987/slas987.pdf
i.e.
P0-R43 to "fixed process flow with user parameters" 0 0 1 1 0

philippe44, 2020-03-14:
Thank you :-)
Initially I added TAS5780 because there was no way to switch off the analogue part of TAS5754 and keep the DAC output (headset) on TAS5754 but Ifinally found a way, so either one or the other is fine.

Unfortunately, to answer your question, I've not been able to do much progress on hybrid flow and how to use it. I've been very busy with updating the HW and developping the SW.

Now I'm not sure by what you mean by "Is it possible ... to use the AMP without it". The AMP works perfectly fine w/o using TI realpath. It works out of the box, no need of TI software. Realpath allows you to tweaks things, which I'd like to do at some point, but don't worry, it works very fine just like that

infnorm, 2020-03-14:
Thanks for the info!

1. by switch off the analog you mean turn off the power amplification so you are just using the amp.

2. as far as "is it possible..to use the AMP without it..." I am surprised as the datasheet and application guide doesn't seem to indicate you can use the tas5754 without using the evaluation
board to get a program. Their software is kind of stupid in that you need an evaluation board to extract a program into a header that has a dump of the registers that can be reloaded from the mcu. But I guess it can work because the default mode on bootup is configured in a way that it just uses some default program or bypasses the dsp portion. It's kind of sad that TI hasn't made the software situation friendly like analog with the adau1701 and other stuff and sigma studio.

philippe44, 2020-03-14:
1- I meant there is a DAC output on the TAS that you loop-in. I use for line-out but I wanted to have the option to switch of the built-in power amplifier when the jack is inserted, but still have the analogue out of course. And it was a bit tricky

2- I agree, but the good thing is that I can re-insure you you don't need any tool to make it work. You just have to send a few commands on the I2C but to configure it your way, but that's very simple (and it's there in my SW project). No need to download complicated path. It's mainly PLL config and of course volume management

philippe44, 2020-10-12:
Closed for inactivity

Closed 2020-10-12.

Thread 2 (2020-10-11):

Marking of Left and Right speaker outputs on SqueezeAMP PCB are swapped

CornelisJ, 2020-10-11:
When playing a channel check test track on SqueezeAMP, I noticed that the markings of the left and right speaker outputs on the SqueezeAMP PCB are swapped. The left channel test signal came from the speaker connected to R+/R-, and the right channel test signal from the speaker connected to L+/L-.

This swap is confirmed by checking the speaker connections on the PCB against information in the datasheet of the TAS5780M DAC+ClassD amplifier. The TAS5780M datasheet states (section 9.4.3.1 on page 54):
By default, the TAS5780M device is configured to output the Right frame of an I2S input signal on the Channel A output and the Left frame on the Channel B output.
However on the SqueezeAMP PCB, SPK_OUTA+/- signals are routed to the speaker terminals marked L+/L- (i.e. via LC low pass filter), and the SPK_OUTB+/- signals are routed to speaker terminals marked R+/R-. So the L/R speaker markings on the PCB are not correct.

Workaround: When connecting speakers to SqueezeAMP, connect the Left speaker to the terminals marked R+/R-, and the Right speaker to the terminals marked L+/L-.

PS: Connection of Left and Right signals on the Line Out Jack are correct.

philippe44, 2020-10-12:
Thanks for reporting that - I've fixed the silk in 3.12

Closed 2020-10-12.

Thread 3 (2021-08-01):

README.md: S2 selects between IO0 and GND (J6)

shaffenmeister, 2021-08-01:
Observation:
README.md states that S2 routes either GND or IO2 to pin 6 of J6.
According to the schematic, S2 routes either GND or IO0 to pin 6 of J6.
IO2 is used for the speaker fault detection.

philippe44, 2021-08-01:
Indeed - Thanks!

Closed 2021-08-01.

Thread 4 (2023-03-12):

Project not available anymore on PCBWay

acabrol, 2023-03-12:
Hello everyone i try to buy the project on PCBWay but it doesn't seem to exist anymore.

Where can I buy a pre-built version or a DIY kit?

philippe44, 2023-03-12:
I don't have spare boards anymore but I will probably do a next batch in the few coming months

emlynmac, 2023-03-23:
I put the gerber files into pcbway and got 5 boards made up for the boost.
I'm awaiting arrival of the boards. If they're good and you want one, I can send you one.

emlynmac, 2023-03-29:
@acabrol My boards arrived; they look good. Let me know if you'd like one (DM me)

Muehsal, 2023-04-01:
Hi there,

I have ordered the normal version with the Gerber files (labeled 3.20 in the repro) and a modified bom & picknplace (also from the repro) without charger and spdif from PCBWay. The SqueezeAmps work perfectly out of the Box (after flashing).

Thank you very much Philippe for sharing the design!

One small note: the silk screen of the 3.20 Gerber states a version 3.11. The diptrace file, however, has a silk screen with 3.20.

Muehsal, 2023-04-01:
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

philippe44, 2023-04-01:
Looks good!

joffito, 2023-06-14:
If anybody got any board (populated / unpopulated) left, i'd happily buy one. cheers and thanks for sharing this great project :)

philippe44, 2023-06-14:
I have plenty of PCBs

joffito, 2023-06-15:
Sounds good :-) How to buy one / contact you? I think the DM message feature is not available in Github?

acabrol, 2023-08-10:
> @acabrol My boards arrived; they look good. Let me know if you'd like one (DM me)

Can you post the updated link to PCBway?

I think i could insert the squeezeamp esp32 in this DIY kit:
https://a.aliexpress.com/_EQdlhwn

agdamsbo, 2023-08-14:
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

@Muehsal Would you be willing to share your modified files? Ive had some troubles with PCBway, but would very much like to try my hands with a board just like the one I see you have ordered.

timotoots, 2024-01-07:
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

I would also be interested in your version. Could you send me this as well? Thanks!

emlynmac, 2024-02-27:
> I have plenty of PCBs

Do you still have any left?
I have a workshop I'm going to run on SMD and I'd like to have a board to be able to stencil on.

philippe44, 2024-02-27:
Yes I do

Closed 2024-10-25.

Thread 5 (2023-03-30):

Cant Open dip dch

r1ckdu, 2023-03-30:
I cannot open the files:
SqueezeAMP-3.20.dch
SqueezeAMP-3.20.dip

I was hoping i could check out the schematics a bit, is there something special i need to do to achieve this?

philippe44, 2023-03-30:
You need to install diptrace (free)

r1ckdu, 2023-03-30:
I have. It says the file is corrupted.

Mar 30, 2023 20:18:36 philippe44 ***@***.***>:

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

r1ckdu, 2023-03-30:
Maybe drop that - i  think this was a stupid error of me not downloading the file correctly, i cloned the whole git and no errors anymore. Closed :)

Closed 2023-03-30.

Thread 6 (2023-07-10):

Boot time + a bunch of functional questions

b0redng33k, 2023-07-10:
I'm looking for options for an Airplay/Bluetooth receiver + MP3 player (from SD Card) with SPDIF (optical) output.

I've found this project along with https://github.com/sle118/squeezelite-esp32 and IIUC it seems to tick most boxes, however, I have a few more questions if you don't mind.

1) What is the boot time ?
2) Can it drive I2C + SPI (LCD) + I2S (or Optical SPDIF) all at once ?
3) Can it be used stand alone ? (i.e.: read MP3 from SD Card controlled via Web interface)
4) How is Bluetooth and Airplay arbitrated ? Let's say I connect to it with my phone over Bluetooth, then I send it audio from the computer via Airplay. Would it switch from Bluetooth to Airplay ? If I stop Airplay would it go back to Bluetooth or do I have to reconnect ?

Right now I'm using a RPi Zero W with Volumio but I'm not happy with boot times, it takes for ever to boot (a few minutes) because it reindexes the MP3s on the SD Card at every boot + sometimes it just crashes.

TIA

philippe44, 2023-07-10:
It takes less than 10 seconds to boot
It can do i2s and one display using i2c or spi but data displayed is basic unless you use LMS
It does not do standalone
BT and AirPlay are basically arbitrated. First come first served.
You can look at @feelfreelinux project for something more standalone

philippe44, 2023-07-13:
It's on the muvox-io repository on GitHub, named euphonium.

Closed 2023-08-11.

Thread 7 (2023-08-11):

Board photo has wrong description for S2

sle118, 2023-08-11:
Picture says IO02/GND toggle for J6 output, but we all know that IO02 is hard coded to speaker fault so this must be IO00, as the picture shows on J6 itself. I was wondering why my rotary wasn't responding with B on GPIO 0 connected to J6 😆

philippe44, 2023-08-11:
fixed

sle118, 2023-08-11:
that was fast!

Closed 2023-08-11.

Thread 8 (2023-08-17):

Please release the latest 3.x version as a release

ElektronikCZ, 2023-08-17:
Im a dummy and i downloaded the 1.5 zip from releases and got it made by pcbway instead of the 3.x (facepalm). Making the latest version a "release" might be handy for other hasty people lol.

philippe44, 2023-08-17:
I will - did you want just the PCB of the fully assembled? I have PCB and I'm preparing an new batch

ElektronikCZ, 2023-08-17:
I wanted a bare PCB to hand assemble. I think the version 1.5 shouldnt be a big issue for me, but ill be more careful next time.

philippe44, 2023-08-17:
There a few changes that matter and I have a few spares of 3.20. It’s just a matter of putting a stamp on an envelope if you want a couple.

Envoyé de mon iPhone

Le 17 août 2023 à 01:32, ElektronikCZ ***@***.***> a écrit :

I wanted a bare PCB to hand assemble. I think the version 1.5 shouldnt be a big issue for me, but ill be more careful next time.

—
Reply to this email directly, view it on GitHub<https://github.com/philippe44/SqueezeAMP/issues/8#issuecomment-1681862964>, or unsubscribe<https://github.com/notifications/unsubscribe-auth/ACKDHV33RWBPUGOAEHRDUZ3XVXJITANCNFSM6AAAAAA3TUK4FA>.
You are receiving this because you commented.Message ID: ***@***.***>

Closed 2024-10-25.

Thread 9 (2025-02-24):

Speaker polarity wrong

bitr0tator, 2025-02-24:
Hi,

the speaker polarity/order in the old gerber and also the new 3.20 gerber update plus in the readme are wrong:

when looking at the bottom side of the pcb (amp side):

in the old layout right and left are mixed but the polarity is correct

old from right/up (square pad) to left/down:

L+ L- R- R+

in the updated 3.20 layout right and left are correct, but the polarity is wrong

3.20 update from right/up (square pad) to left/down:

R- R+ L+ L-

but correct it should be:

R+ R- L- L+

please update the gerber files and the readme:

J5: speaker connector

    1: R+ (square pad)
    2: R-
    3: L-
    4: L+

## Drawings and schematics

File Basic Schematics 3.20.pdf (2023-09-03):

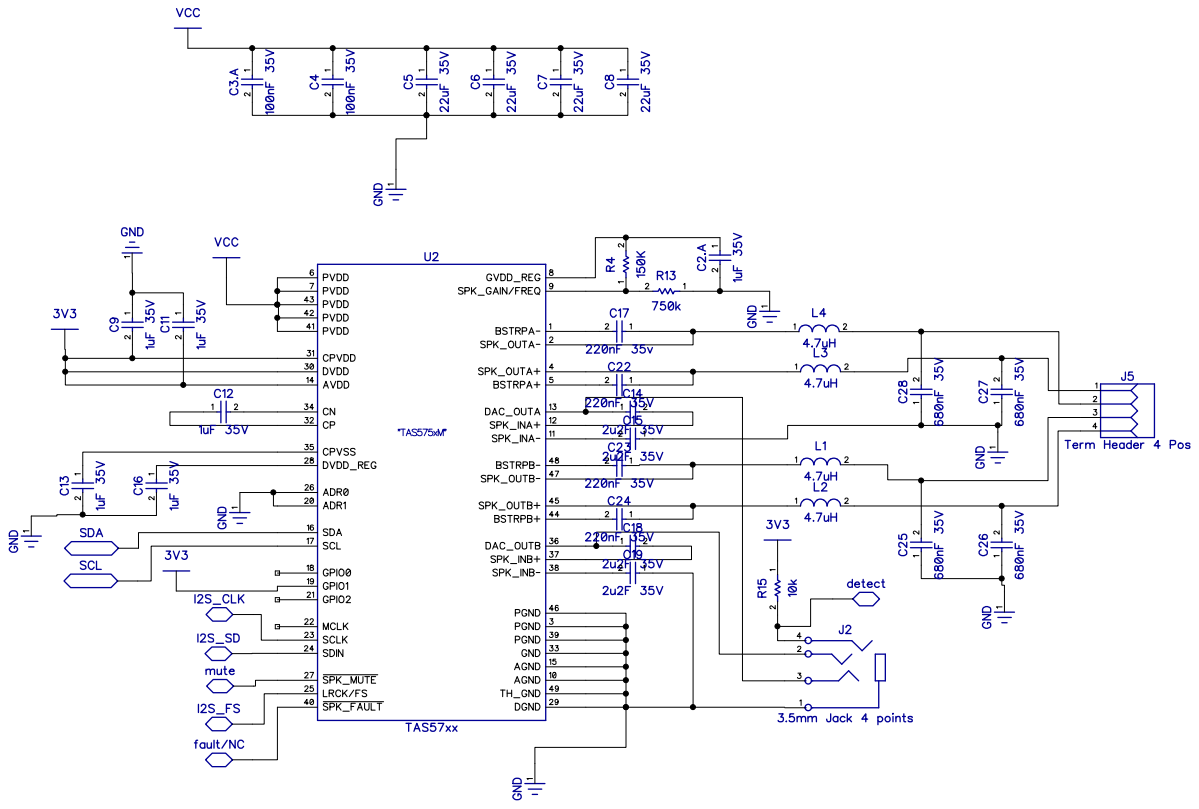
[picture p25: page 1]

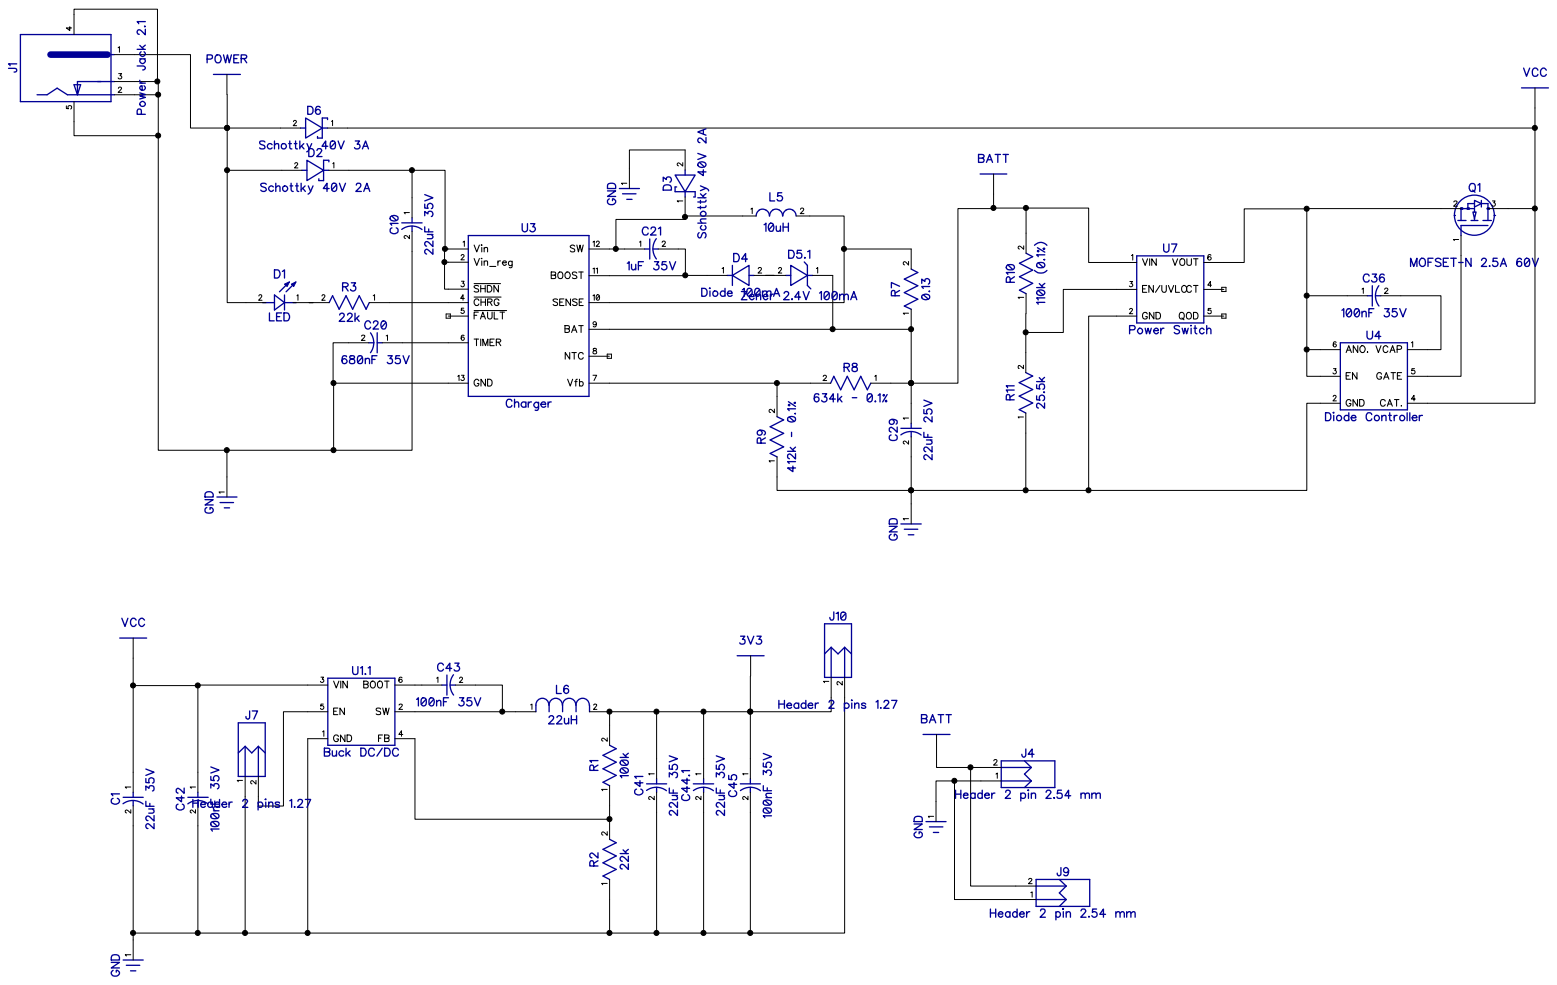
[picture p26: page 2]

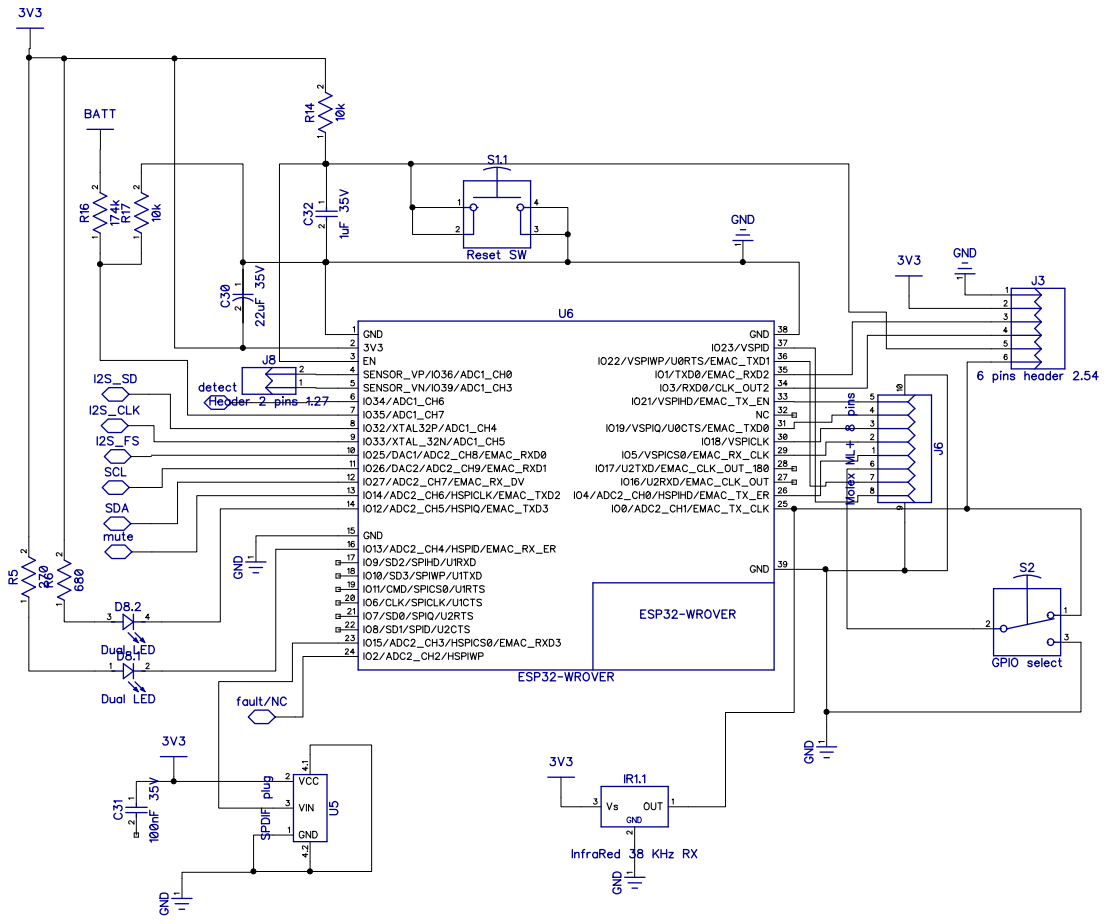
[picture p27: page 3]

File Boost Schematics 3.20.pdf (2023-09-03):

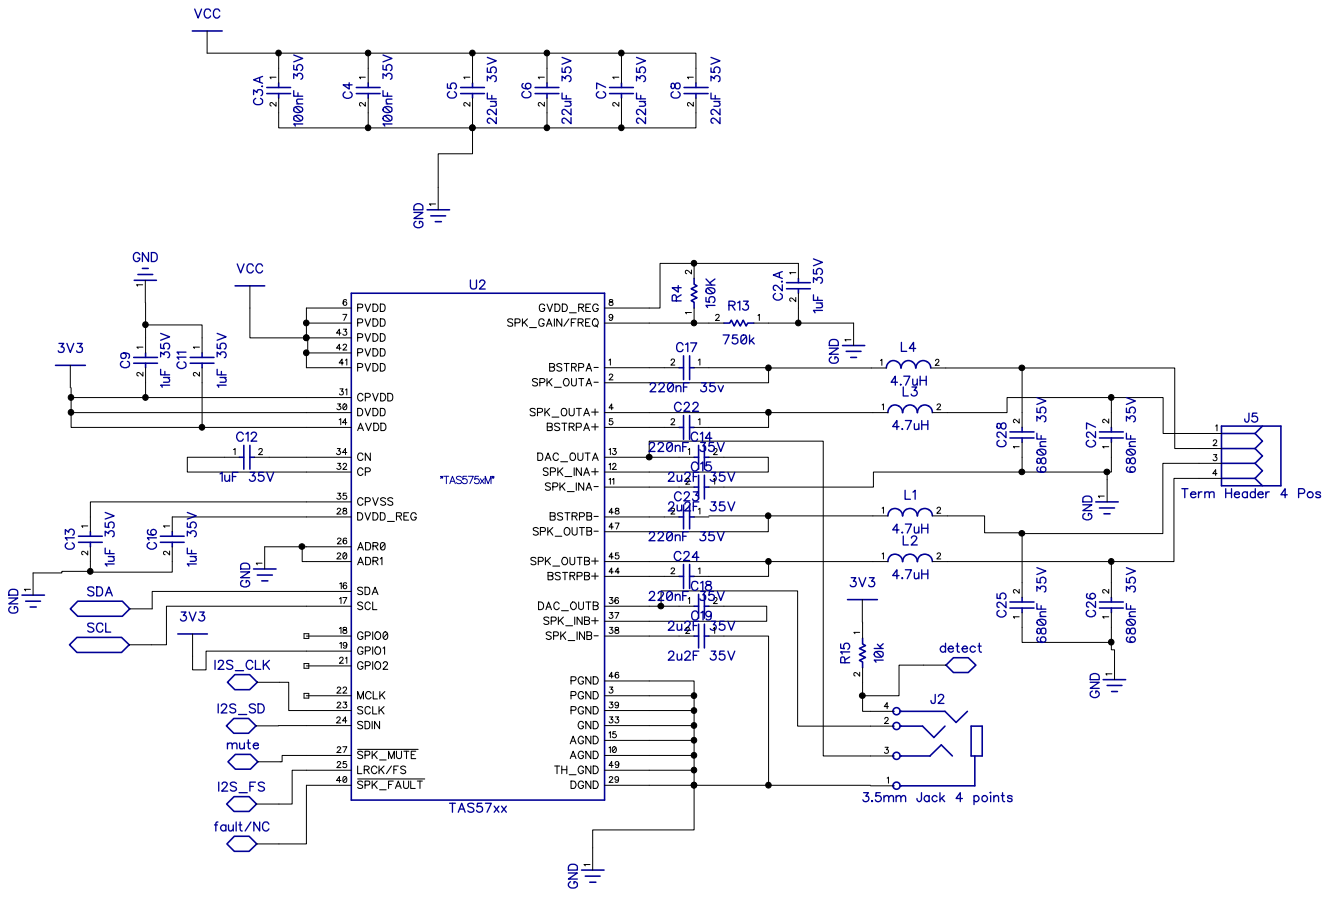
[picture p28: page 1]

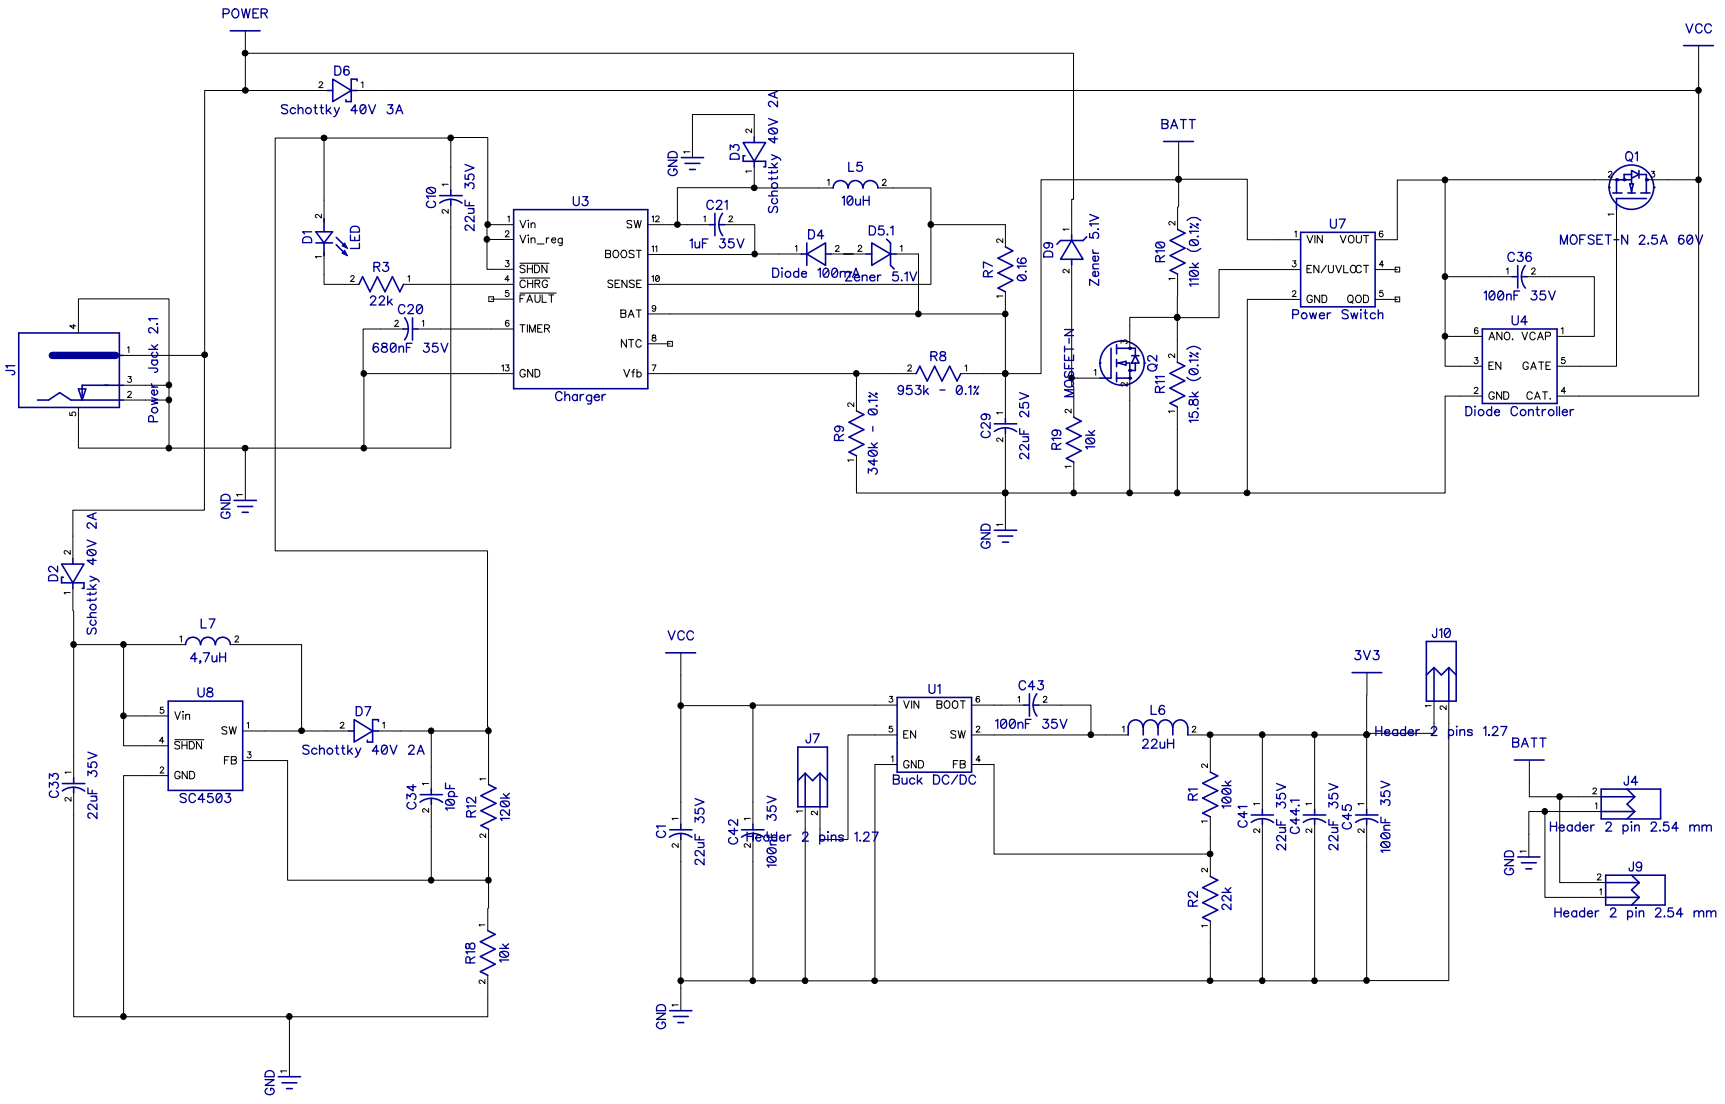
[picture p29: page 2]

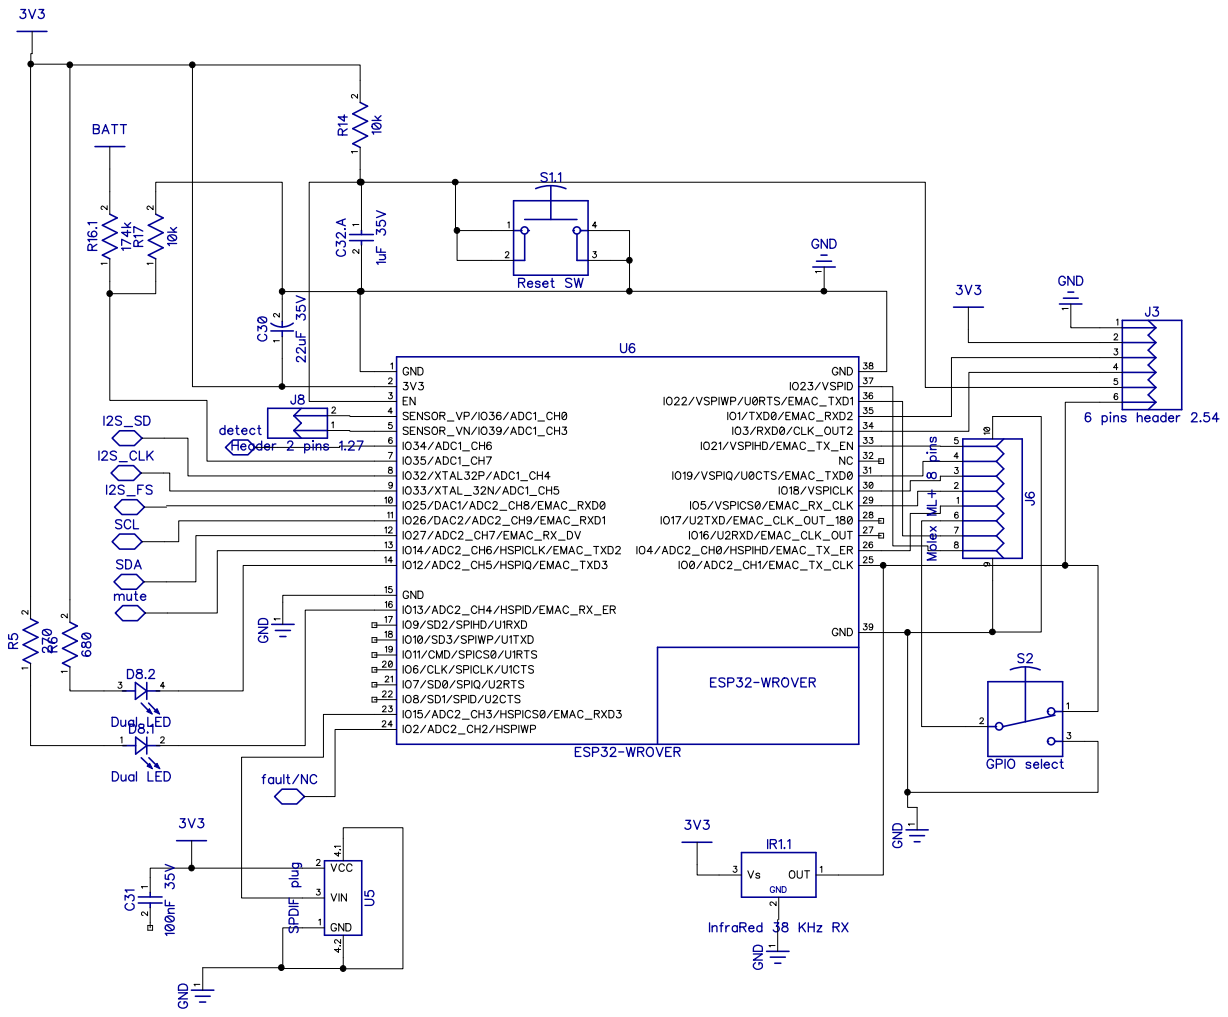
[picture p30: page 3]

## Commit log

2019-10-06 initial commit
    initial commit
    add pictures
    update
    README update
    README update
    update README
    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
    [SqueezeAMP-boost.csv, SqueezeAMP.csv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]
2019-11-06 Update README.md
    update + add casing
    Update README.md
    caseing update
    Boost update
    Update README.md
    Update README.md
    Update README.md
    add DigiKey BOM
    Update README.md
    Update README.md
    Delete Answer Material problem-T-F21W273808F--W273808FSF20.xlsx
    Delete Updated- W273808FSF20-30sets-SqueezeAMP-1.31 2019-10-7-1.xlsx
    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
    [1mm taller lid with vent.stl, 2x18500.stl, 3x18350.stl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]
2019-12-16 add version 2.0 with TAS578x
    [DigiKey-Boost.csv, DigiKey.csv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]
2020-01-13 Add version 3.0 & correct TAS SPKFAULT wrong pinout on all designs
    [BoardOutline.gbr, Bottom.gbr, BottomMask.gbr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]
2020-03-16 Update references
    [DigiKey-Boost.csv, DigiKey.csv, SqueezeAMP-boost.csv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]
2020-05-18 update gerber files
    [Bottom.gbr, BottomMask.gbr, BottomPaste.gbr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]
2020-05-18 update basic BOM
    [SqueezeAMP.csv]
2020-05-18 correct BOMs
    [SqueezeAMP-boost.csv]
2020-05-18 J4/J9 clarification
    [SqueezeAMP-boost.csv, SqueezeAMP.csv]
2020-05-18 clean gerber
    [Pick&Place.csv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]
2020-05-18 clean gerber files
    [Pick&Place.csv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]
2020-05-25 incorrect references for feedback resistors
    [SqueezeAMP.csv]
2020-10-12 fix R/L silk
    [Pick&Place.csv]
2021-03-26 reversed connector
2023-01-31 3.20 update
    [BoardOutline.gbr, Bottom.gbr, BottomMask.gbr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]
2023-09-03 add schematics in PDF
2023-10-29 adding a few files for 3D printing
    [Revised Box Jan 2021 with top option 3.step, V2 - Back.stl, V2 - Front.stl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]
2023-10-29 cleanup case names
    [V1 - .stl, V1 - 2x18500.stl, V1 - 3x18350.stl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]
2023-10-29 remove useless step
    [V2 - Revised Box Jan 2021 with top option 3.step]
2023-10-29 fixing names
    [V2 - All Parts (3D adjusted, no logo).dxf, V2 - Revised Box Jan 2021.dxf]
